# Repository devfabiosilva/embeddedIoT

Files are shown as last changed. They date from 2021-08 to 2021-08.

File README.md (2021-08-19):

# embeddedIoT
My old project for IoT and automation 8 bit system

## Brief

This is my fisrt and old discontinued home embedded 8bit iot for control, monitoring and automation working 24/7 since 2014 open hardware

## Details

### - Hardware specification

  - Project [folder](/hardware)
  - Last update 2014-04-01

  TODO

### - Firmware specification

  - Project [folder](/firmware_ver1.5)
  - Last update 2015-07-01

### - Uart for IoT using PySerial (Monitoring)

  - Project [folder](/UartForIoT)
  - RS232 protocol using [PySerial](https://pypi.org/project/pyserial/)
  - Script type reads events RS232 -> USB -> TCP
  - Commands using [this reference for reading events](/embeddedsystem.pdf) pages: 32-35
  TODO

## Snapshots

<p align="center">
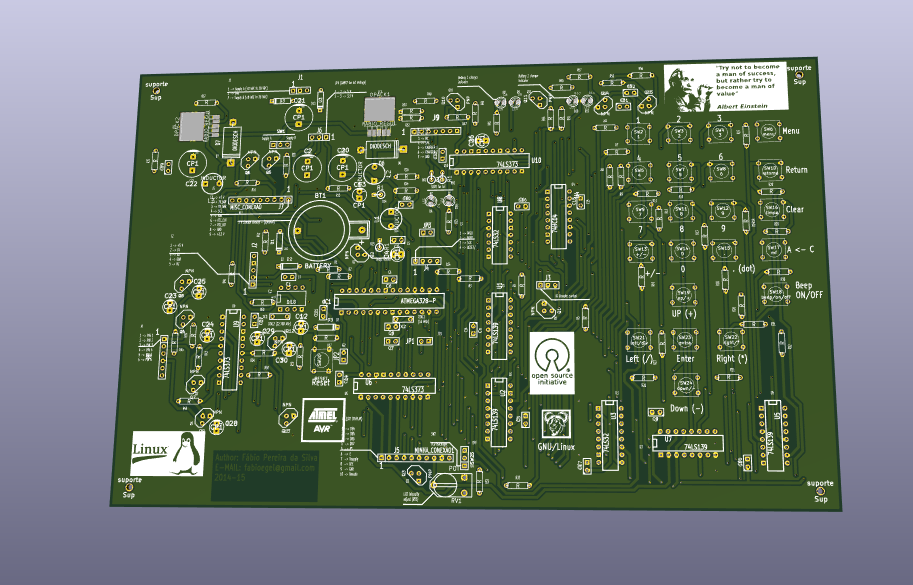
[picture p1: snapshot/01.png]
  
</p>

<p align="center">
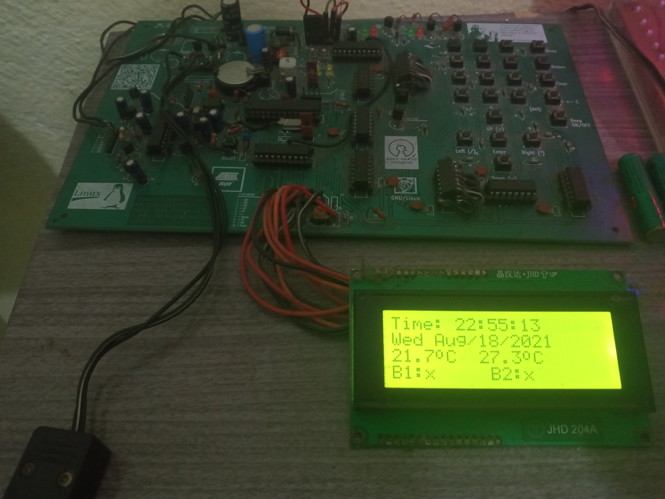
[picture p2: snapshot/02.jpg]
  
</p>

## Specifications

## Export GERBER files

## Installing AVR C (avr-gcc) and compiling firmware

## Upload firmware

## Running Python to read events from RS 232

## License

  - MIT

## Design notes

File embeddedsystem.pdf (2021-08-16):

## An 8-bit AVR EMBEDDED SYSTEM

## Features

- Six independent pins automation through IR remote control, keyboard or IoT.
- Six independent programmable pins controlled by temperature, battery charger sensors and timers
- Real time clock with alarm
- Calendar
- Default and Scientific Calculator
- 20x4 LCD display
- Two Battery Charger
- Bilingual language support (English/Portuguese)
- 16 MHz MCU clock speed using ATMEGA 328pu microcontroller
- Full IR control available through ProntoHEX code allowing access through IR devices.
- Automotive, Home and Industry versions available in a single hardware
- Low cost components

Author: Fábio Pereira da Silva 03/29/2015

Rev.: 2

1

"Try not to become a man of success, but rather try to become a man of value

Albert Einstein

2

Figure 1: Basic Block Diagram

## Overview

This Embedded System was developed with ATMEGA 8-bit family microcontroller. Due to its capacity of processing it's possible to do amazing stuffs. This Embed System is an automated controller that you can control 6 (six) home/industry appliances individually easily by temperature, timer and by user through infrared (remote control or cellphone) or even IoT (optional). In Figure 1 is seen the basic block using ATMEGA 328pu 8-bit microcontroller.

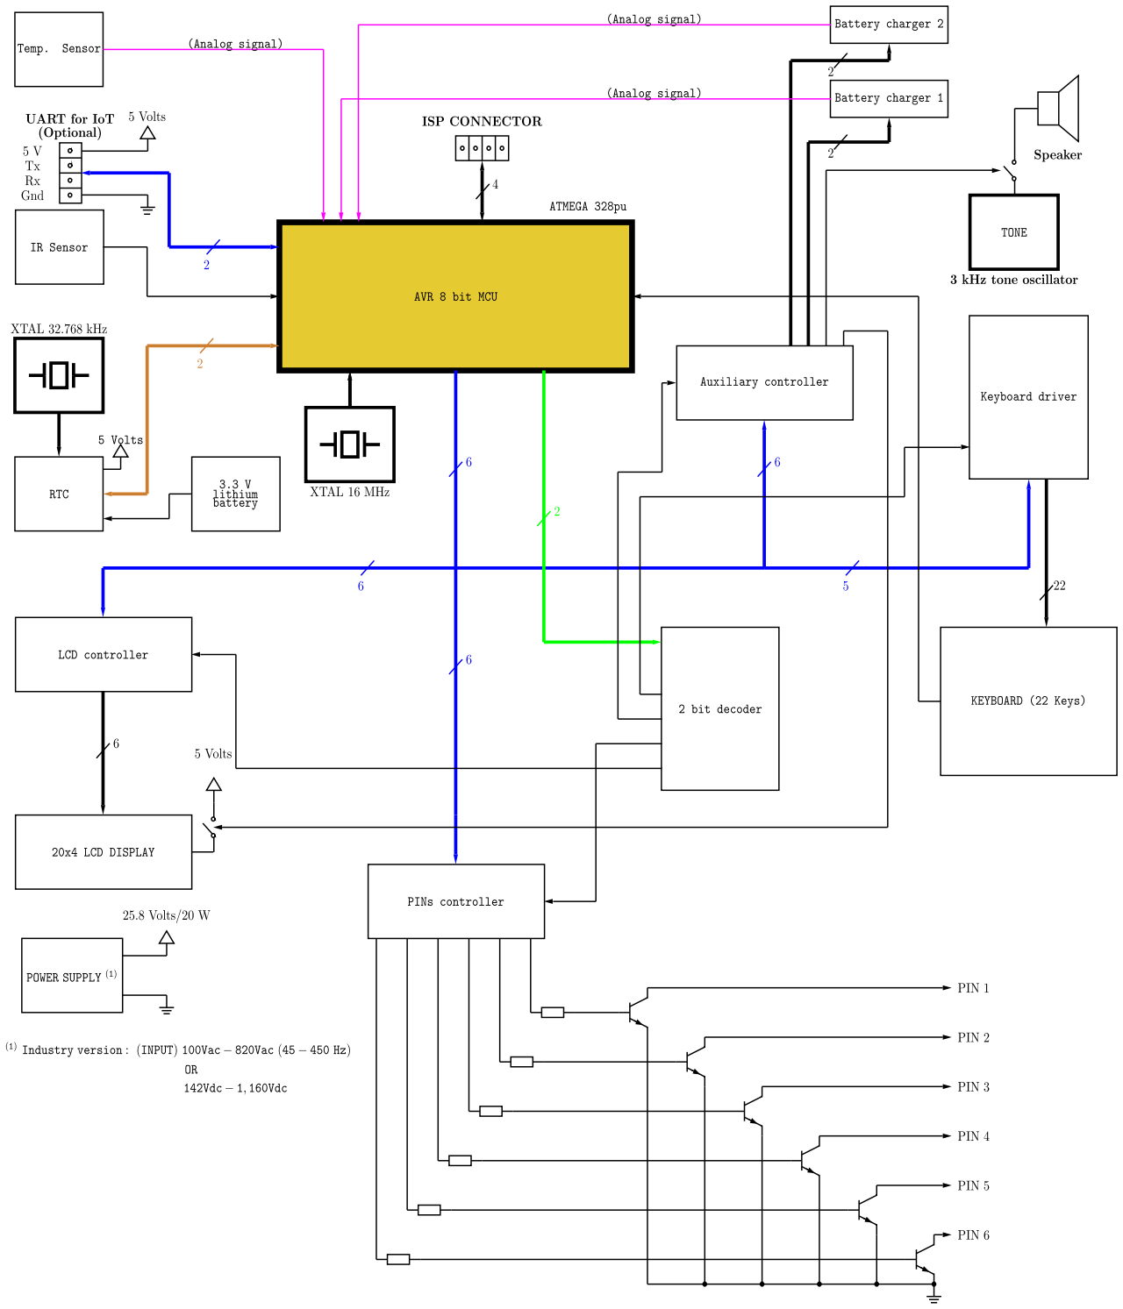
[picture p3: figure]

3

## Hardware interface and connections

Before turn on this Embedded System you should know this hardware interface and basic connections. Figure 2 shows this 8-bit Embedded System Hardware.

10

Figure 2: 8-bit hardware AVR architecture

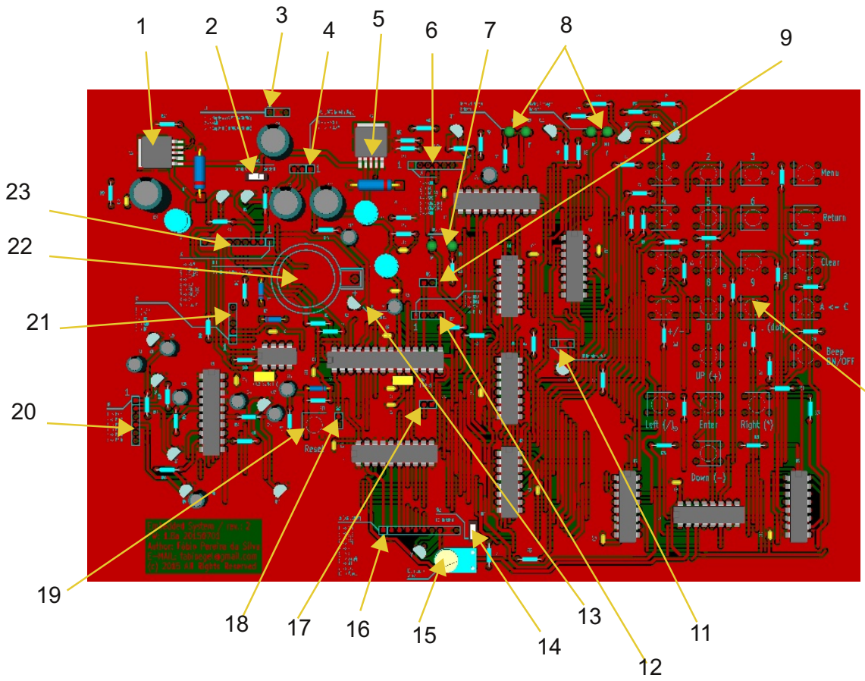
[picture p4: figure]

Table 1 shows detailed connections name and descriptions of the Figure 2.

4

## Hardware settings

You need configure hardware to interface other devices. This hardware also provides two post regulated power supply 3.3 V (2 A) and 5 V (1.5 A) to others devices such as Arduino, Raspberry PI, Beagle Bone and many others from 8 Vdc ~ 38 Vdc (automotive application) and 100 Vac ~ 820 Vac (45-450 Hz) or even 142 Vdc to 1160 Vdc (Home and Industrial application) using a special high range SMPS (Switching Mode Power Supply) designed by me.

| Name | Description
1 | 3.3 V regulator | Provides 3.3 V (2 A) to external devices
2 | SW1 Input power selector | Selects one of two inputs power supply (A or B)
3 | 2 (two) Input power | Input A and B => Power supply voltage 8 Vdc to 38 Vdc
4 | JP4 (UART2 for IoT Voltage) | Selects operation voltage (3.3 V or 5V) for UART2 for IoT
5 | 5 V regulator | Provides 5 V (1.5 A) for internal and external circuit devices
6 | J8 output interface | Output interface (Battery 1 and 2 chargers and Speaker)
7 | RX and TX indicator leds | Indicates Rx and Tx transmitting data
8 | Battery 1 and 2 indicator leds | Indicates Battery 1 and 2 status
9 | JP3 | Normal operation= (short) / ISP programming = (open)
10 | Keyboard | Numerical and functions keyboard
11 | IR (Infrared Sensor) | For remote control access
12 | J3 (ISP interface) | For ISP interface (firmware update/debug/programming)
13 | T1 | External temperature sensor
14 | SW2 | LCD Backlight Switch
15 | RV1 | LCD intensity adjust
16 | J4 | Output LCD interface
17 | JP1 | Normal operation= (short) / ISP programming = (open)
18 | JP2 | Normal operation= (short) / ISP programming = (open)
19 | Reset button | Resets microcontroller
20 | J6 | PIN's output interface
21 | J2 | UART for IoT interface
22 | Real time clock backup | Lithium Battery (optional) for Real Time Clock (RTC)
23 | J5 | Input/Output interface

## Table 1: Connections name and descriptions

5

This devices offers 9 connectors to interface others components or devices

Tables 2, 3, 4, 5, 6, 7 and 8 shows each input/output interface.

J1 | Input type | Description
1 | Power supply A | Input voltage 8 Vdc to 38 Vdc
2 | GND | Ground
3 | Power Supply B | Input voltage 8 Vdc to 38 Vdc

## Table 2: Input power supply connection (J1)

J2 (UART1 for IoT) Input/output type | | Description
1 | +5 V | Output power supply
2 | Tx (Output) | UART1 for IoT transmit
3 | Rx (Input) | UART1 for IoT receive
4 | GND | Ground
5 | NC | No connection
J3 (ISP Programming) | Input/output type | Description
1 | MISO (output) | Data output
2 | MOSI (Input) | Data input
3 | SCK (Input) | Clock from master from programmer
4 | RESET (Input) | Reset inverted logic from programmer

## Table 3: UART1 for IoT and +5 V supply connection (J2)

## Table 4: ISP connection (J3)

6

J4 (LCD display interface) | Output type | Description
1 ~ 4 | DB4 ~ DB7 | Four high order bits for HD44780 LCD controller
5 | RS | Select register
6 | E | Data write
7 | Vsupply | +5 V Power supply for LCD controller
8 | VEE | LCD intensity
9 | GND | Ground
10 | Vanode | +5 V power supply for LCD backlight
J5 (I/O interface) | Input/Output type | Description
1 | +5 V (output) | Output power supply. Provides 1.5 A for external devices
2 | TX (output) | Inverted output (UART2 for IoT)
3 | RX (input) | Inverted input (UART2 for IoT)
4 | SCL (output) | Output I 2C clock
5 | SDA (input/output) | Input/output I 2C data
6 | RTC_CLK (output) | Real time clock frequency (32.768 Hz, 1024 Hz, 32 Hz or 1Hz) Refer PCF 8563 for details
7 | RTC_INT (output open drain) | Inverted real time clock interrupt. Refer PCF 8563 for details
8 | GND | Ground
9 | +3.3 V (output) | Output power supply. Provides 2 A for external devices.

## Table 5: LCD display interface connection (J4)

## Table 6: Input/Output interface connection (J5)

7

J6 (PINs output) | Output type | Description
1~6 | PIN1~PIN6 (output open collector) | Provides 90 mA (each pin) output driver. Maximum voltage is 40 V
J7 (Output interface) | Output type | Description
1 | GND | Ground
2 | NC | No connection
3 | NC | No connection
4 | SPK | Speaker
5 | CHARGER 1 | Battery Charger 1 output (47 mA inicial charger current)
6 | CHARGER 2 | Battery Charger 2 output (47 mA inicial charger current)
7 | GND | Ground

## Table 7: Output interface connection (J6)

## Table 8: Output interface connection (J7)

8

## Turning on this Embedded System

After turn on the system will shown in LCD display the following message (Figure 3).

Current time hh:mm:ss

Current date

External
temperature sensor
T1

indicator

Internal (MCU)
temperature sensor T2
indicator

Battery 1 (B1

) charger
indicator in % charging. 'x' for no battery.

Battery 2 (B2

) charger
indicator in % charging. 'x' for no battery.

## Accessing Menu for settings

When pressing <MENU> button will shown 6 (six) options. Press 1 to access Time adjust, weekday (calendar) or alarm, 2 for pins configuration, 3 for detailed sensor measures, 4 for default or scientific calculator, 5 for (others) language support, temperature sensor, and configure UART for IoT, security, UART parity and user password. Finally press 6 for about firmware and hardware information. Full access at UART is limited. Only ROOT has full access by keyboard or remote control.

Figure 3: Embedded System Display

Figure 4: Embedded System inicial MENU

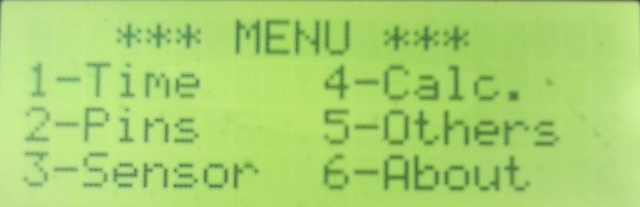
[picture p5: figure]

9

## Setting date and time

To set date/time press <MENU> buttom and press 1 (one) for Time and 1 (one) again to set Date/Time adjust.

Figure 5: DATE and TIME ADJUST

Current date in
yyyy/mm/dd

Current time in
hh:mm:ss

Cursor for typing Date and Time

## Example for Date/Time Adjust

If you want to set Time and Date to May, 14/2015 12:30:00 you must to type 20150514123000 and press <OK> button. You must type yyyymmddhhmmss where yyyy is current year, mm is current month, dd is current day, hh is current hour, mm is current minute and finally ss is current second. If you type anything wrong just press <CLEAR> button to clean Date/Time Adust. For year range is 1900 to 2099.

Figure 6: Date and time adjust example

Figure 7: EXAMPLE: Setting time and date to 12:30:00 May 14, 2015

10

## Weekday (calendar)

To access Weekday press <MENU> > press <1> (Time) > press <2> (Weekday). Display will show a cursor for Weekday command (figure 7 below).

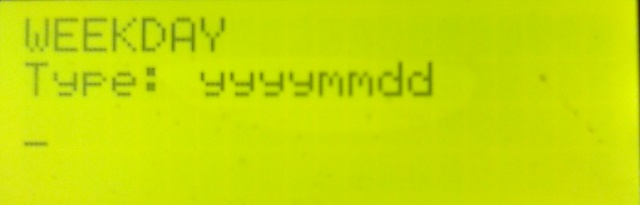
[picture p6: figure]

You must type yyyymmdd for yyyy year mm for month and dd for day

Example:

Which day was July, 4 1776? If you want to know, you must type 17760704 and press <OK> button. The answer is (Thu). It was on Thuesday.

Figure 7: Calendar (weekday)

Figure 8: Calendar example date (July, 6 1776)

## Alarm Setup

To configure alarm just press <MENU> > 1 (Time) > and finally press 3 (alarm) the following message will appear at LCD screen.

Command type: chhmm:

Where:
c = 0 (alarm disabled); c=1 (alarm enabled) hh for hour and mm for minutes

Last alarm in EEPROM memory

Figure 9: Alarm setup

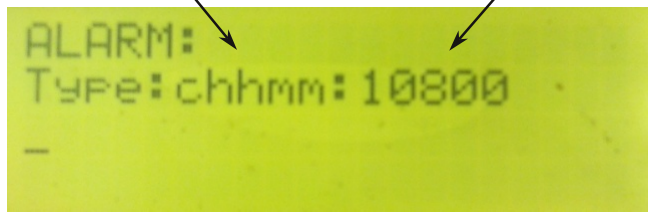
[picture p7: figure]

11

Example 1:

If you type 11910 the alarm will set for 19:10.

Example 2:

To turn off alarm just type 0 and press <OK>.

Figure 10: EXAMPLE: Setting alarm

Figure 11: EXAMPLE: Reset alarm

## Configuring PIN's

This Embedded System has 6 (six) PIN's that can be controlled individually by remote control using Pronto HEX code, remotely by IoT using commands from UART for IoT, by onboard keyboard, by sensors (4 sensors) or time. Each output PIN has two state (ON/OFF) and is open collector port that supports maximum voltage of 40 V and can drive maximum input current of 90 mA.

Figure 12: PIN's configuration menu

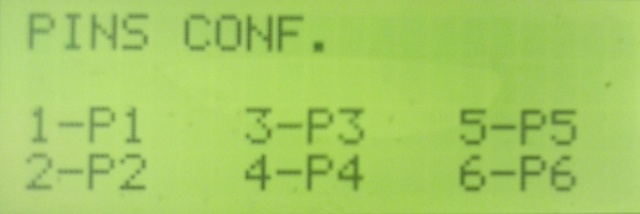
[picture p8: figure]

12

- Timer command:

To configure any pins to turn ON and/or OFF by timer you must type the following

Example 1 for timer command:

If you type 11235210016 and press <OK> button, the pin (in this example PIN 3 in figure 13 below) will always turn ON at 23:52 and always turn OFF at 00:16.

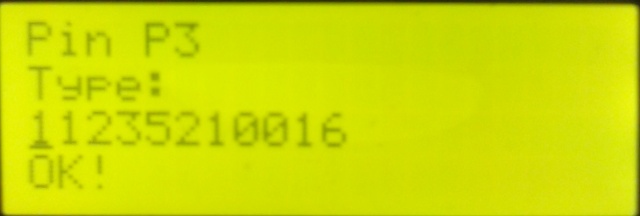
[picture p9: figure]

Example 2 for timer command:

If you type 11201800000 and press <OK> button, the pin (in this example PIN 5 in figure 14 below) will always turn ON at 20:18 (only). Y=0 (turn OFF command is DISABLED)

Figure 13: Timer command Example 1

Figure 14: Timer command Example 2

13

Example 3 for timer command:

If you type 10000011325 and press <OK> button, the pin (in this example PIN 1 in figure 15) will always turn OFF at 13:25 (only). X=0 (turn ON command is DISABLED).

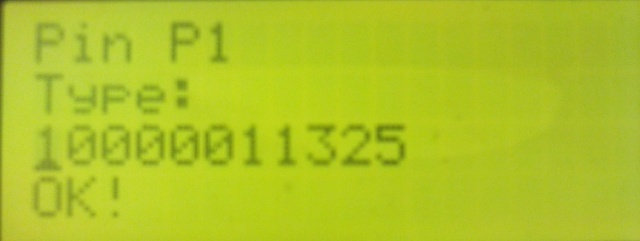
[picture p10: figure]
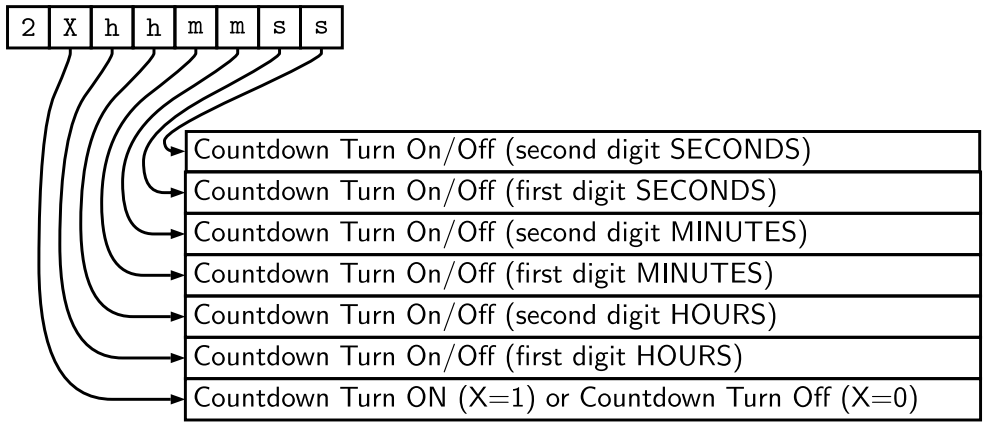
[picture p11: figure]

Example 1 for countdown timer command:

If you type 20001530 and press <OK> button, the pin (in this example PIN 6 in figure
16) will turn off after 15 minutes and 30 seconds (countdown timer).
- Countdown timer command:

To configure any pins to turn ON and/or OFF by countdown just type the following command 2 X h h m m s s for desired pin(s), where:

Figure 15: Timer command Example 3

Figure 16: Countdown timer command Example 1

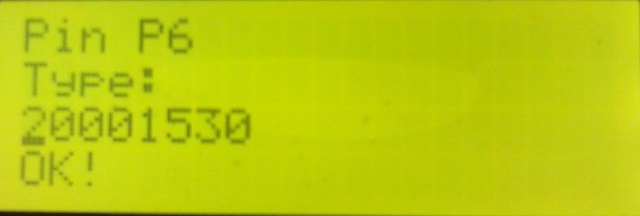
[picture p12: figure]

14

Example 2 for countdown timer command:

If you type 21010000 and press <OK> button, the pin (in this example PIN 6 in figure
17) will turn on after 1 hour (countdown timer). Maximun countdown timer operation is also programmable for 17h59m59s.
- Ciclic (periodic) command:

To configure any pins to turn ON and OFF periodicly, just type the following command 3 h1

h1 m1 m1

s1

s1

h2

h2 m2 m2

s2

s2

for desired pin(s), where:

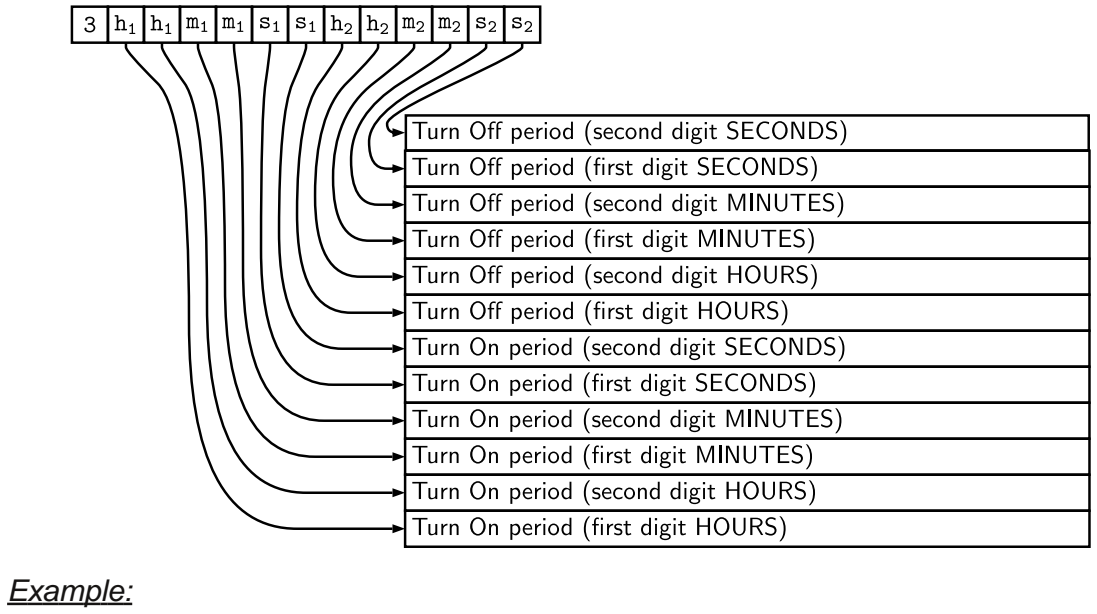
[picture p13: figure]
Example:

If you type 3000001000001 and press <OK> button, the pin (in this example PIN 6 in figure 18) will keep ON each 1 (one) second and will keep OFF each 1 (one) second. In other words, PIN 6 in this configuration oscillates at 1/2 Hertz. Maximun ciclic operation is also programmable for 17h59m59s.

Figure 17: Countdown timer command Example 2

15

## Temperature sensor command ( T1

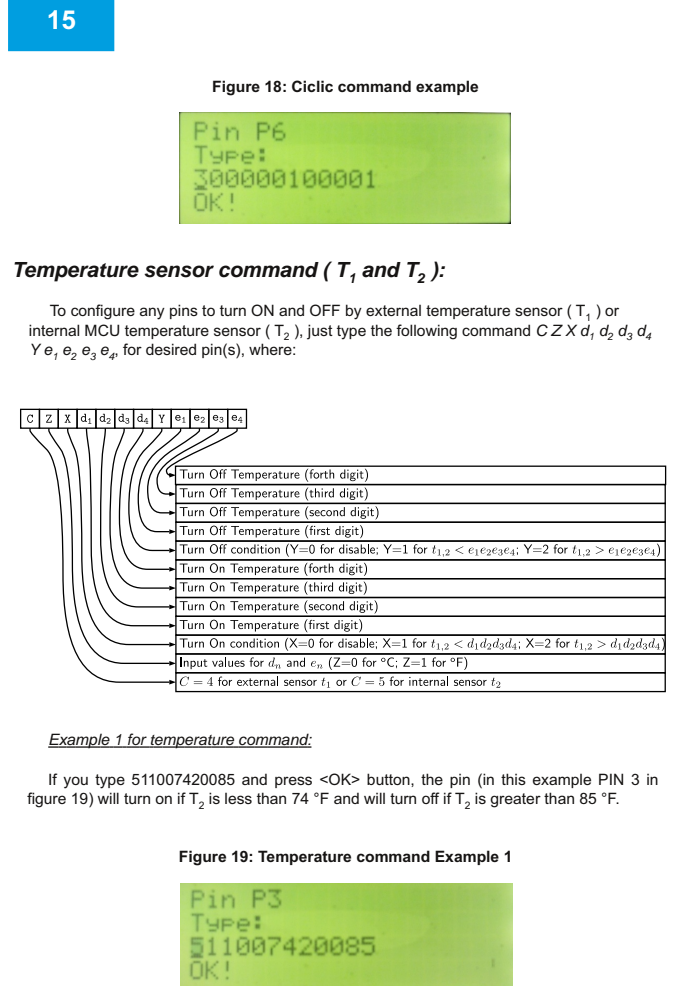
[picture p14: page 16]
and T2

Figure 18: Ciclic command example

To configure any pins to turn ON and OFF by external temperature sensor ( T1
internal MCU temperature sensor ( T2

), just type the following command C Z X d1

, for desired pin(s), where:

Example 1 for temperature command:

If you type 511007420085 and press <OK> button, the pin (in this example PIN 3 in
figure 19) will turn on if T2

is less than 74 °F and will turn off if T2

is greater than 85 °F.

Figure 19: Temperature command Example 1

16

Example 2 for temperature command:

If you type 51200001-040 and press <OK> button, the pin (in this example PIN 5 in figure 20) will turn on if T2

is greater than 0 °F and will turn off if T2

is less than -40 °F.

## Battery charger sensor command ( B1

## and B2

):

To configure any pins to turn ON and/or OFF by battery sensor B1

or B2

, just type the
following command.

Figure 20: Temperature command Example 2

Example 3 for temperature command:

If you type 402003500000 and press <OK> button, the pin (in this example PIN 6 in figure 21) will turn on if T1

is greater than 35 °C. NOTE: turn off condition (Y=0) is disable. Then turn on (only) is enabled.

Figure 21: Temperature command Example 3

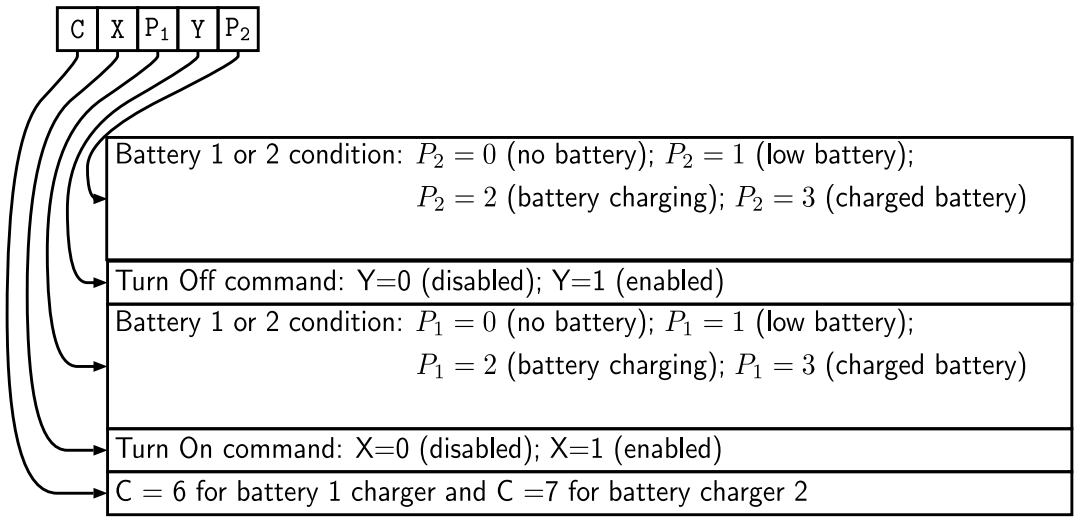
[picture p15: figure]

17

Example 1 for battery charge command:

If you type 61113 and press <OK> button, the pin (in this example PIN 3 in figure 22) will turn on if battery in charger 1 is uncharged and will turn off if battery in charger 1 is charged.

Figure 22: Battery charger example 1

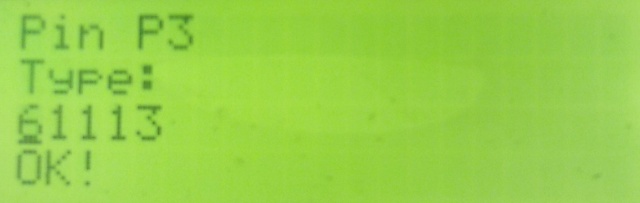
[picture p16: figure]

Example 2 for battery charger:

If you type 71310 and press <OK> button, the pin (in this example PIN 4 in figure 23) will turn on if battery in charger 2 is charged and will turn off if battery in charger 2 is released.

Example 3 for battery charger:

If you type 60013 and press <OK> button, the pin (in this example PIN 6 in example 24) will turn off if battery in charger 1 is charged.

Figure 23: Battery charger example 2

Figure 24: Battery charger example 3

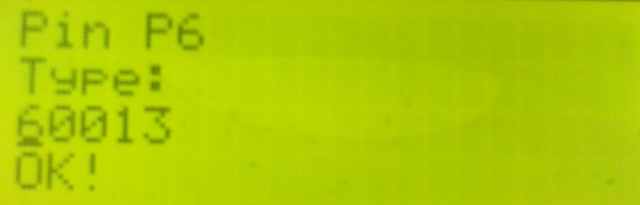
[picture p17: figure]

18

## Resetting pin(s)

If you want to reset any pin(s), just type 0 and press <OK>. Now pin will be controlled only by user from IoT, Infrared or Keyboard.

Example:

If you type 0 and press <OK>. The pin (in this example PIN 6 in figure 25) will be controlled by user via IoT, remote control or keyboard.

## Sensor panel

To access real time sensors press <MENU> and press <3> (Sensor). The system will provide measurements of four sensors (Battery 1 and 2 charger voltage, internal (MCU) and external temperature T1 and T2 respectively).

Figure 25: Resetting pin(s)

Figure 26: Sensor panel (real time measuring)

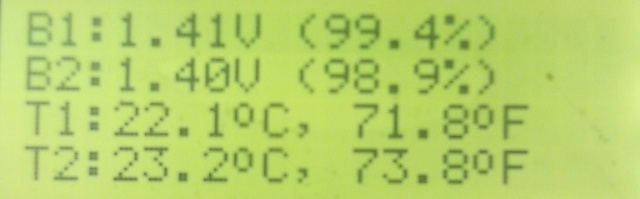
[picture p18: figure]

## Calculator menu

To access calculator option just type <MENU> > <4> (Calc.). Default and Scientific calculator provides 3 (three) variables A (or 'x'), B and C where A (or 'x') is first value, B is second value and C is result of operation. Input and result values are in float point unit is (32 bits) or 7 digit precision.

19

## Default calculator

To access default calculator just press <MENU> > <4> (Calc.) > <1> (Default calculator).

In default calculator is possible perform 4 (four) math basic operations (+) addition, () subtraction, (*) multiply and (/) divide.

Example:

If you want divide 50 by 3 you type <5> > <0> > <enter> and then press <divide> and then press <3> and <enter> result is shown in figure 28.

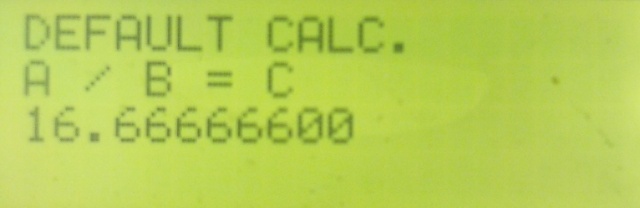
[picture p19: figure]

## Scientific calculator

There are 23 math functions: exp(x), ln(x), ln(x)/C, sqrt(x), cbrt(x), sin(x), cos(x), tan(x), sind(x), cosd(x), tand(x), asin(x), acos(x), atan(x), asind(x), acosd(x), atand(x), C<-A, hyp(C, A), mod(C,A), sinh(x), cosh(x) and tanh(x).

Some examples: Printing in the screen some basics values.

Example 1 for scientific calculator:

If you press <up> or <down> and select exp function and type <1> and press <enter>. Result is an approximation of e = 2.7182817...

Figure 27: Calculator menu

Figure 28: Basic calculator example

20

Example 2 for scientific calculator

If you press <up> or <down> and select sqrt function and type <2> and press <enter>. Result is an approximation of ≈ 1.4142135...

Example 3 for scientific calculator

Calculating π using trigonometric function in this case acos(-1)= π = 3.1415927...

Figure 29: Scientific calculator example 1

Figure 30: Scientific calculator example 2

Figure 31: Scientific calculator example 3

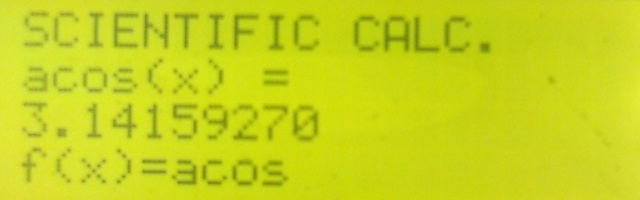
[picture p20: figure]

Example 4 for scientific calculator

But now, if you want to calculate log10

(2)? This scientific calculator does not provide such function but you can calculate easily using two steps by using one logarithm property:

step 1: Select ln(x) function and type 10 and press <enter>. Result, in this case ln(10) is stored in variable C.
step 2: Select ln(x)/C function and type 2 and press <enter>. Result is an approximation of log10
(2)=0.30102998...

21

Example 5 for scientific calculator

But now, if you want to calculate hypotenuse of 3 and 6? To calculate it you must call function C<-A and call hyp(C, A) using two steps because you have to pass two variables
(3) and (6).
step 1: Select C<-A function and type 3 and press <enter>. Value 3 is stored in C variable.
step 2: Select hyp(C,A) function and type 6 and press <enter>. Result is an approximation of hyp(3,6)=6.7082038...

Figure 32: Scientific calculator example 4 (step 1)

Figure 33: Scientific calculator example 4 (step 2)

Figure 34: Scientific calculator example 5 (step 1)

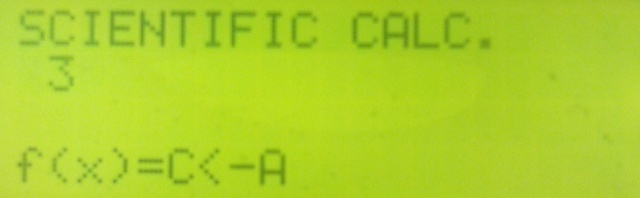
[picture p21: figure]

Figure 35: Scientific calculator example 5 (step 2)

22

## Changing language system

To change language interface you must first access other functions menu. So you must type <MENU> > <5> > <1> and select your available language (US English) or (Brazilian Portuguese). Press <1> for English (US) or press <2> for Portuguese (BR).

## Other configuration

To access other configuration to have special access like language interface, change unity measurements, configure IoT and security you must type <MENU> > <5> and then you will see as figure below (figure 36).

Figure 36: Other configurations (special options)

Figure 37: Selecting language interface

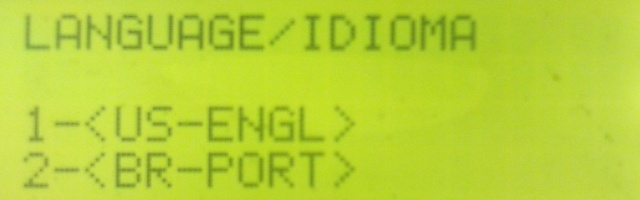
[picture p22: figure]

## Temperature measurements

You can read temperature sensors T1 (external) and T2 (MCU internal) in (°C) degree Celsius (default) or in (°F) degree Fahrenheit. To modify both temperature indicator type <MENU> > <5> > <2>. Then choose 1 (for °C) or (2 for °F).

Figure 38: Selecting realtime system measurement

23

## UART for IoT

You can use UART for IoT to access this embedded system to control PINs output, read or write SRAM and EEPROM memories, LCD control, read sensors, reset MCU, configure hardware and read or set date and time remotely. To have entire or partial control for remote control via IoT you must access UART for IoT option. You can do it only locally (ROOT). For details see (UART for IoT user security).

To have an access to UART for IoT you must type <MENU>, <5> > <3>.

If you set a password then it will be requested every time you access UART for IoT menu. See setting password for details.

In UART for IoT Menu, there are 3 (three) options: 1 (configure port), 2 (Security attributes), 3 (Set PASSWORD)

## Configure port menu

If you want to access UART for IoT you must before configure speed, parity, security attributes and user password (optional)

Figure 39: Access UART for IoT (with password)

Figure 40: Access UART for IoT (no password)

Figure 41: Configure port menu

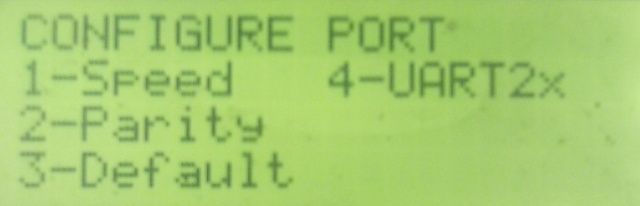
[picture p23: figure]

24

## Setting speed to UART for IoT

To set speed (baund rate) just type in UART for IoT menu <1> > <1>. Default value is 5 (19600 bps). Table 9 below shows 16 values of UART speed available.

Speed | Baund rate (bps)

0 300

1 600

2 1200

3 2400

4 4800

5 9600 (default)

6 14400

7 19200

8 28800

9 38400

10 50000

11 76800

12 230400

13 250000

14 500000

15 1000000

## Table 9: UART for IoT speed

Figure 42: Setting speed

25

## Parity settings

To set parity just type in UART for IoT menu <1> and <2>. There are 3 options available: 1- None (default), 2 Even and 3 Odd. User can modify these settings for error detection in UART communication port.

Figure 43: Setting parity

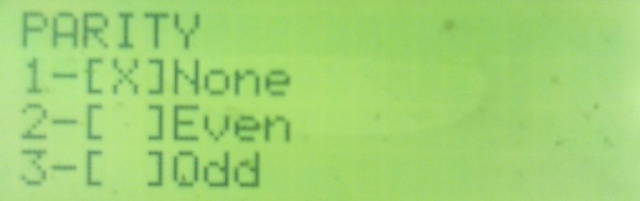
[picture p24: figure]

## Loading defaut values

To load default values, just type in UART for IoT menu <1> and <3>. A message "Load default?" with two answer available will apear: 1- Yes and 2 No. If you type 1 (Yes), all the configurations port will set to default (Speed = 5, Parity = None and UART2x=Disabled).

Figure 44: Load default option

## Enabling/Disabling UART2x

You can simply double (2x) speed communication to UART. To access UART2x press in UART for IoT menu <1> (Configure port) and <4> (UART2x). Press 1 to Enable UART2x or 2 to Disable UART2x. If UART2x is enabled, communication speed in Table 9 will be multiplied by 2 and the new range will be (600 to 2,000,000 bauds/s). Default value to UART2x = Disabled. UART for IoT PORT 2 will not work at highest speed due to hardware limitations. Even in PORT 1 errors may occur in high speed communication.

Figure 45: Enable/Disable UART2x

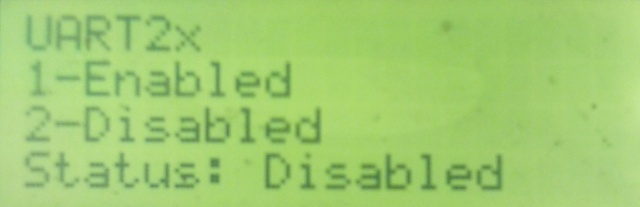
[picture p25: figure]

26

Function | Description | Values
x | No function (reserved) | Don't care 0 or 1
N | Read sensors | N=0b0 (access denied), N=0x1 (read all sensors)
T | Two wire access | T=0b0 (access denied), T=0b1 (Two wire read and write access)
S1S0 | SRAM access | S1S0 =0b00 (access denied), S1S0 =0b01 (read only), S1S0 =0b10 (write only), S1S0 =0b11 (read/write)
En | UART for IoT access | En=0b0 (UART for IoT) disable, En=0b1 (UART for IoT) enebled.
F | Program (FLASH) (read only) | F=0b0 (access denied), F=0b1 (FLASH read only enabled)
R | Reset MCU | R=0b0 (reset MCU disabled), R=0b1 (reset MCU enabled)
E1E0 | EEPROM access | E1E0 =0b00 (access denied), E1E0 =0b01 (read only), E1E0 =0b10 (write only), E1E0 =0b11 (read/write)
P1P0 | PIN access | P1P0 =0b00 (access denied), P1P0 =0b01 (read only), P1P0 =0b01 (write only), P1P0 =0b11 (read/write)
L | LCD access/control | L=0b0 (access denied), L=0b1 (LCD control access/control)
D1D0 | Date and time access | D1D0 =0b00 (access denied), D1D0 =0b01 (read only), D1D0 =0b10 (write only), D1D0 =0b11 (read write)

## UART for IoT user security

User can control remote access from read/write and access command using permission configuration. For security access into UART for IoT menu type <2> (Security attributes) <1> (Permission).

You can access FLAG value (16 bits) stored in EEPROM at address 0x3FE (low bits) and 0x3FF (high bits). Each bit(s) has an especial attribute for access, read or write commands for UART for IoT. See Table 10 for permission bits details. User value is present in decimal and hexadecimal see figure 46 below.

Flag | N | T | x | S1 | S0 | En | F | R | E1 | E0 | P1 | P0
x | L | D1 | D0
MSB | LSB
15 | 0

Figure 46: 16 bit security flags for remote access

## Table 10: Flag bits function and description

27

## Setting user PASSWORD

For managing (set, modify, clear) user password type into UART for IoT menu 3-> Set PASSWORD.

Figure 47: Setting IoT security

## UART for IoT user security (load default)

For default values of security attributes type into UART for IoT menu 2-> (Security attributes) 2- Default. Will apear "Load default?" question. Then type 1 for Yes (Load default) or 2 (No) to keep user security settings.

Default value is FLAG=33873 (0x8451). This means UART for IoT is enabled for read only Pins, Datetime, EEPROM memory and user can access all sensors.

Figure 48: Load default option

Figure 49: Setting user PASSWORD

If there is no Password or it's your first time setting password then will appear a message below (Figure 50). And then you will need to type the old password.

28

## Information about firmware and hardware

If you type <MENU> > <6> you have access to information about current firmware and hardware date and version. Firmware is upgradable by ISP (In Serial Programming) interface.

Type your new password and press <ENTER>. A confirm message password will appear and type <ENTER>. User password now is set. Now, you will need password to access UART for IoT.

Figure 50: Setting a new PASSWORD

Figure 51: Retyping a new PASSWORD

Figure 52: About information

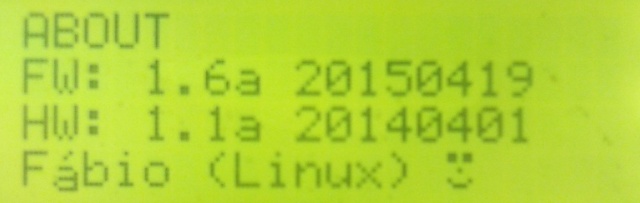
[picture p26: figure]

29

## Characteristics

CPU architecture: AVR 8-bit RISC

CPU speed: 16 MHz

Total memory: 32 kB (Flash)

Total SRAM memory: 2 kB

Total EEPROM memory: 1 kB

Interrupts: 6 interrupts (3 external + 3 internal)

Hardware Version: 1.1a (20140401)

Firmware Version: 1.5a (20150419) (upgradable via ISP interface)

Languages support: English (USA) / Portuguese (Brazil)

Temperature unity measurements: °F (degree Fahrenheit) or °C (degree Celsius)

Operation voltages:

8 to 38 Vdc

Lithium Battery 3.3 V (optional) for Real Time Clock

Industry and Home Version*:100Vac 820Vac (45-450Hz) or 142Vdc 1160Vdc

*A Very High Voltage Range Switching Mode Power Supply for Embedded System. See documentation for details. This power supply uses only 3 (three) transistors e no integrated circuits.

30

Code IR | Pronto Hex code
0 | 0000 0066 0000 006b 0168 00b3 0017 0017 0017 0017 0017 0017 0017 0017 0017 0017 0017 0017 0017 0017 0017 0017 0017 0017 0001 002c 0017 0017 0001 002c 0017 0017 0001 002c 0017 0017 0001 002c 0017 0017 0001 002c 0017 0017 0001 002c 0017 0017 0001 002c 0017 0017 0001 002c 0017 0017 0017 0017 0017 0017 0017 0017 0001 002c 0017 0017 0017 0017 0017 0017 0001 002c 0017 0017 0017 0017 0001 002c 0017 0017 0001 002c 0017 0017 0001 002c 0017 0017 0017 0017 0001 002c 0017 0017 0001 002c 0017 0017 0017 0017 0001 002c 0017 0017 0001 002c
1 | 0000 0066 0000 006b 0168 00b3 0017 0017 0017 0017 0017 0017 0017 0017 0017 0017 0017 0017 0017 0017 0017 0017 0017 0017 0001 002c 0017 0017 0001 002c 0017 0017 0001 0030 0017 0017 0001 002c 0017 0017 0001 002c 0017 0017 0001 002c 0017 0017 0001 002c 0017 0017 0001 002c 0017 0017 0001 002c 0017 0017 0017 0017 0017 0017 0001 002c 0017 0017 0017 0017 0017 0017 0017 0017 0017 0017 0017 0017 0001 002c 0017 0017 0001 002c 0017 0017 0017 0017 0001 002c 0017 0017 0001 002c 0017 0017 0001 002c 0017 0017 0001 002c 0017 0017 0001 002c
2 | 0000 0066 0000 006b 0168 00b3 0017 0017 0017 0017 0017 0017 0017 0017 0017 0017 0017 0017 0017 0017 0017 0017 0017 0017 0001 002c 0017 0017 0001 002c 0017 0017 0001 002c 0017 0017 0001 002c 0017 0017 0001 002c 0017 0017 0001 002c 0017 0017 0001 002c 0017 0017 0001 002c 0017 0017 0001 002c 0017 0017 0017 0017 0001 002c 0017 0017 0001 002c 0017 0017 0001 002c 0017 0017 0017 0017 0017 0017 0017 0017 0017 0017 0001 002c 0017 0017 0017 0017 0017 0017 0017 0017 0001 002c 0017 0017 0001 002c 0017 0017 0001 002c 0017 0017 0001 002c
3 | 0000 0066 0000 006b 0168 00b3 0017 0017 0017 0017 0017 0017 0017 0017 0017 0017 0017 0017 0017 0017 0017 0017 0017 0017 0001 002c 0017 0017 0001 002c 0017 0017 0001 002c 0017 0017 0001 002c 0017 0017 0001 002c 0017 0017 0001 002c 0017 0017 0001 002c 0017 0017 0001 002c 0017 0017 0001 002c 0017 0017 0001 002c 0017 0017 0001 002c 0017 0017 0001 002c 0017 0017 0001 002c 0017 0017 0017 0017 0017 0017 0017 0017 0017 0017 0017 0017 0017 0017 0017 0017 0017 0017 0001 002c 0017 0017 0001 002c 0017 0017 0001 002c 0017 0017 0001 002c
4 | 0000 0066 0000 006b 0168 00b3 0017 0017 0017 0017 0017 0017 0017 0017 0017 0017 0017 0017 0017 0017 0017 0017 0017 0017 0001 002c 0017 0017 0001 002c 0017 0017 0001 002c 0017 0017 0001 002c 0017 0017 0001 002c 0017 0017 0001 002c 0017 0017 0001 002c 0017 0017 0001 002c 0017 0017 0001 002c 0017 0017 0017 0017 0017 0017 0001 002c 0017 0017 0001 002c 0017 0017 0017 0017 0017 0017 0017 0017 0017 0017 0001 002c 0017 0017 0001 002c 0017 0017 0017 0017 0017 0017 0001 002c 0017 0017 0001 002c 0017 0017 0001 002c 0017 0017 0001 002c
5 | 0000 0066 0000 006b 0168 00b3 0017 0017 0017 0017 0017 0017 0017 0017 0017 0017 0017 0017 0017 0017 0017 0017 0017 0017 0001 002c 0017 0017 0001 002c 0017 0017 0001 002c 0017 0017 0001 002c 0017 0017 0001 002c 0017 0017 0001 002c 0017 0017 0001 002c 0017 0017 0001 002c 0017 0017 0001 002c 0017 0017 0001 002c 0017 0017 0017 0017 0001 002c 0017 0017 0001 002c 0017 0017 0017 0017 0017 0017 0017 0017 0017 0017 0017 0017 0001 002c 0017 0017 0017 0017 0017 0017 0001 002c 0017 0017 0001 002c 0017 0017 0001 002c 0017 0017 0001 002c
6 | 0000 0066 0000 006b 0168 00b3 0017 0017 0017 0017 0017 0017 0017 0017 0017 0017 0017 0017 0017 0017 0017 0017 0017 0017 0001 002c 0017 0017 0001 002c 0017 0017 0001 002c 0017 0017 0001 002c 0017 0017 0001 002c 0017 0017 0001 002c 0017 0017 0001 002c 0017 0017 0001 002c 0017 0017 0001 002c 0017 0017 0017 0017 0017 0017 0017 0017 0001 002c 0017 0017 0017 0017 0017 0017 0017 0017 0017 0017 0001 002c 0017 0017 0001 002c 0017 0017 0001 002c 0017 0017 0017 0017 0001 002c 0017 0017 0001 002c 0017 0017 0001 002c 0017 0017 0001 002c
7 | 0000 0066 0000 006b 0168 00b3 0017 0017 0017 0017 0017 0017 0017 0017 0017 0017 0017 0017 0017 0017 0017 0017 0017 0017 0001 002c 0017 0017 0001 002c 0017 0017 0001 002c 0017 0017 0001 002c 0017 0017 0001 002c 0017 0017 0001 002c 0017 0017 0001 002c 0017 0017 0001 002c 0017 0017 0001 002c 0017 0017 0001 002c 0017 0017 0001 002c 0017 0017 0017 0017 0001 002c 0017 0017 0017 0017 0017 0017 0017 0017 0017 0017 0017 0017 0017 0017 0001 002c 0017 0017 0017 0017 0001 002c 0017 0017 0001 002c 0017 0017 0001 002c 0017 0017 0001 002c
8 | 0000 0066 0000 006b 0168 00b3 0017 0017 0017 0017 0017 0017 0017 0017 0017 0017 0017 0017 0017 0017 0017 0017 0017 0017 0001 002c 0017 0017 0001 002c 0017 0017 0001 002c 0017 0017 0001 002c 0017 0017 0001 002c 0017 0017 0001 002c 0017 0017 0001 002c 0017 0017 0001 002c 0017 0017 0017 0017 0001 002c 0017 0017 0017 0017 0017 0017 0001 002c 0017 0017 0017 0017 0017 0017 0017 0017 0001 002c 0017 0017 0017 0017 0001 002c 0017 0017 0001 002c 0017 0017 0017 0017 0001 002c 0017 0017 0001 002c 0017 0017 0001 002c 0017 0017 0001 002c
9 | 0000 0066 0000 006b 0168 00b3 0017 0017 0017 0017 0017 0017 0017 0017 0017 0017 0017 0017 0017 0017 0017 0017 0017 0017 0001 002c 0017 0017 0001 002c 0017 0017 0001 002c 0017 0017 0001 002c 0017 0017 0001 002c 0017 0017 0001 002c 0017 0017 0001 002c 0017 0017 0001 002c 0017 0017 0017 0017 0001 002c 0017 0017 0001 002c 0017 0017 0017 0017 0001 002c 0017 0017 0017 0017 0017 0017 0017 0017 0001 002c 0017 0017 0017 0017 0017 0017 0001 002c 0017 0017 0017 0017 0001 002c 0017 0017 0001 002c 0017 0017 0001 002c 0017 0017 0001 002c
. (dot) | 0000 0066 0000 006b 0168 00b3 0017 0017 0017 0017 0017 0017 0017 0017 0017 0017 0017 0017 0017 0017 0017 0017 0017 0017 0001 002c 0017 0017 0001 002c 0017 0017 0001 002c 0017 0017 0001 002c 0017 0017 0001 002c 0017 0017 0001 002c 0017 0017 0001 002c 0017 0017 0001 002c 0017 0017 0017 0017 0017 0017 0017 0017 0017 0017 0017 0017 0017 0017 0001 002c 0017 0017 0017 0017 0001 002c 0017 0017 0001 002c 0017 0017 0001 002c 0017 0017 0001 002c 0017 0017 0001 002c 0017 0017 0001 002c 0017 0017 0017 0017 0001 002c 0017 0017 0001 002c
+/ | 0000 0066 0000 006b 0168 00b3 0017 0017 0017 0017 0017 0017 0017 0017 0017 0017 0017 0017 0017 0017 0017 0017 0017 0017 0001 002c 0017 0017 0001 002c 0017 0017 0001 002c 0017 0017 0001 002c 0017 0017 0001 002c 0017 0017 0001 002c 0017 0017 0001 002c 0017 0017 0001 002c 0017 0017 0017 0017 0017 0017 0001 002c 0017 0017 0017 0017 0017 0017 0017 0017 0017 0017 0017 0017 0001 002c 0017 0017 0001 002c 0017 0017 0017 0017 0001 002c 0017 0017 0001 002c 0017 0017 0001 002c 0017 0017 0001 002c 0017 0017 0001 002c 0017 0017 0001 002c
<enter> | 0000 0066 0000 006b 0168 00b3 0017 0017 0017 0017 0017 0017 0017 0017 0017 0017 0017 0017 0017 0017 0017 0017 0017 0017 0001 002c 0017 0017 0001 002c 0017 0017 0001 002c 0017 0017 0001 002c 0017 0017 0001 002c 0017 0017 0001 002c 0017 0017 0001 002c 0017 0017 0001 002c 0017 0017 0001 002c 0017 0017 0017 0017 0017 0017 0001 002c 0017 0017 0017 0017 0017 0017 0001 002c 0017 0017 0017 0017 0017 0017 0001 002c 0017 0017 0001 002c 0017 0017 0017 0017 0001 002c 0017 0017 0001 002c 0017 0017 0017 0017 0001 002c 0017 0017 0001 002c
Up (+) | 0000 0066 0000 006b 0168 00b3 0017 0017 0017 0017 0017 0017 0017 0017 0017 0017 0017 0017 0017 0017 0017 0017 0017 0017 0001 002c 0017 0017 0001 002c 0017 0017 0001 002c 0017 0017 0001 002c 0017 0017 0001 002c 0017 0017 0001 002c 0017 0017 0001 002c 0017 0017 0001 002c 0017 0017 0017 0017 0017 0017 0001 002c 0017 0017 0001 002c 0017 0017 0017 0017 0017 0017 0001 002c 0017 0017 0017 0017 0001 002c 0017 0017 0001 002c 0017 0017 0017 0017 0017 0017 0001 002c 0017 0017 0001 002c 0017 0017 0017 0017 0001 002c 0017 0017 0001 002c
Down () | 0000 0066 0000 006b 0168 00b3 0017 0017 0017 0017 0017 0017 0017 0017 0017 0017 0017 0017 0017 0017 0017 0017 0017 0017 0001 002c 0017 0017 0001 002c 0017 0017 0001 002c 0017 0017 0001 002c 0017 0017 0001 002c 0017 0017 0001 002c 0017 0017 0001 002c 0017 0017 0001 002c 0017 0017 0017 0017 0017 0017 0017 0017 0017 0017 0017 0017 0017 0017 0017 0017 0017 0017 0001 002c 0017 0017 0001 002c 0017 0017 0001 002c 0017 0017 0001 002c 0017 0017 0001 002c 0017 0017 0001 002c 0017 0017 0001 002c 0017 0017 0001 002c 0017 0017 0001 002c
Left (/) | 0000 0066 0000 006b 0168 00b3 0017 0017 0017 0017 0017 0017 0017 0017 0017 0017 0017 0017 0017 0017 0017 0017 0017 0017 0001 002c 0017 0017 0001 002c 0017 0017 0001 002c 0017 0017 0001 002c 0017 0017 0001 002c 0017 0017 0001 002c 0017 0017 0001 002c 0017 0017 0001 002c 0017 0017 0001 002c 0017 0017 0017 0017 0001 002c 0017 0017 0017 0017 0001 002c 0017 0017 0017 0017 0017 0017 0017 0017 0017 0017 0001 002c 0017 0017 0017 0017 0001 002c 0017 0017 0017 0017 0001 002c 0017 0017 0001 002c 0017 0017 0001 002c 0017 0017 0001 002c
Right (*) | 0000 0066 0000 006b 0168 00b3 0017 0017 0017 0017 0017 0017 0017 0017 0017 0017 0017 0017 0017 0017 0017 0017 0017 0017 0001 002c 0017 0017 0001 002c 0017 0017 0001 002c 0017 0017 0001 002c 0017 0017 0001 002c 0017 0017 0001 002c 0017 0017 0001 002c 0017 0017 0001 002c 0017 0017 0001 002c 0017 0017 0017 0017 0001 002c 0017 0017 0001 002c 0017 0017 0017 0017 0017 0017 0017 0017 0017 0017 0017 0017 0001 002c 0017 0017 0017 0017 0017 0017 0001 002c 0017 0017 0001 002c 0017 0017 0001 002c 0017 0017 0001 002c 0017 0017 0001 002c

31

Code IR | Pronto Hex code (continued)
Menu | 0000 0066 0000 006b 0168 00b3 0017 0017 0017 0017 0017 0017 0017 0017 0017 0017 0017 0017 0017 0017 0017 0017 0017 0017 0001 002c 0017 0017 0001 002c 0017 0017 0001 002c 0017 0017 0001 002c 0017 0017 0001 002c 0017 0017 0001 002c 0017 0017 0001 002c 0017 0017 0001 002c 0017 0017 0017 0017 0017 0017 0001 002c 0017 0017 0017 0017 0001 002c 0017 0017 0017 0017 0001 002c 0017 0017 0017 0017 0001 002c 0017 0017 0001 002c 0017 0017 0017 0017 0001 002c 0017 0017 0017 0017 0001 002c 0017 0017 0017 0017 0001 002c 0017 0017 0001 002c
Return | 0000 0066 0000 006b 0168 00b3 0017 0017 0017 0017 0017 0017 0017 0017 0017 0017 0017 0017 0017 0017 0017 0017 0017 0017 0001 002c 0017 0017 0001 002c 0017 0017 0001 002c 0017 0017 0001 002c 0017 0017 0001 002c 0017 0017 0001 002c 0017 0017 0001 002c 0017 0017 0001 002c 0017 0017 0001 002c 0017 0017 0017 0017 0001 002c 0017 0017 0001 002c 0017 0017 0017 0017 0017 0017 0001 002c 0017 0017 0017 0017 0017 0017 0001 002c 0017 0017 0017 0017 0017 0017 0001 002c 0017 0017 0001 002c 0017 0017 0017 0017 0001 002c 0017 0017 0001 002c

Clear

A < C | 0000 0066 0000 006b 0168 00b3 0017 0017 0017 0017 0017 0017 0017 0017 0017 0017 0017 0017 0017 0017 0017 0017 0017 0017 0001 002c 0017 0017 0001 002c 0017 0017 0001 002c 0017 0017 0001 002c 0017 0017 0001 002c 0017 0017 0001 002c 0017 0017 0001 002c 0017 0017 0001 002c 0017 0017 0017 0017 0001 002c 0017 0017 0001 002c 0017 0017 0001 002c 0017 0017 0017 0017 0017 0017 0017 0017 0017 0017 0001 002c 0017 0017 0017 0017 0017 0017 0017 0017 0001 002c 0017 0017 0001 002c 0017 0017 0001 002c 0017 0017 0001 002c 0017 0017 0001 002c
Beep On-Off | 0000 0066 0000 006b 0168 00b3 0017 0017 0017 0017 0017 0017 0017 0017 0017 0017 0017 0017 0017 0017 0017 0017 0017 0017 0001 002c 0017 0017 0001 002c 0017 0017 0001 002c 0017 0017 0001 002c 0017 0017 0001 002c 0017 0017 0001 002c 0017 0017 0001 002c 0017 0017 0001 002c 0017 0017 0017 0017 0001 002c 0017 0017 0017 0017 0001 002c 0017 0017 0001 002c 0017 0017 0017 0017 0017 0017 0017 0017 0001 002c 0017 0017 0017 0017 0001 002c 0017 0017 0017 0017 0017 0017 0001 002c 0017 0017 0001 002c 0017 0017 0001 002c 0017 0017 0001 002c

32

Command | Description | Code (HEX) | Response (on success) | Response (on error)
Send '0' | Sends '0' key | [0x30] | [ACK] | [NACK]
Send '1' | Sends '1' key | [0x31] | [ACK] | [NACK]
Send '2' | Sends '2' key | [0x32] | [ACK] | [NACK]
Send '3' | Sends '3' key | [0x33] | [ACK] | [NACK]
Send '4' | Sends '4' key | [0x34] | [ACK] | [NACK]
Send '5' | Sends '5' key | [0x35] | [ACK] | [NACK]
Send '6' | Sends '6' key | [0x36] | [ACK] | [NACK]
Send '7' | Sends '7' key | [0x37] | [ACK] | [NACK]
Send '8' | Sends '8' key | [0x38] | [ACK] | [NACK]
Send '9' | Sends '9' key | [0x39] | [ACK] | [NACK]
Send [+/] | Sends [+/] key | [0x3A] | [ACK] | [NACK]
Send [.] | Sends [.] (dot) key | [0x3B] | [ACK] | [NACK]
Send [UP or +] | Sends [UP or +] key | [0x3C] | [ACK] | [NACK]
Send [Down or ] | Sends [Down or ] key | [0x3D] | [ACK] | [NACK]
Send [Right or *] | Sends [Right or *] key | [0x3E] | [ACK] | [NACK]
Send [Left or /] | Sends [Left or /] key | [0x3F] | [ACK] | [NACK]
Send [ENTER] | Sends [ENTER] key | [0x40] | [ACK] | [NACK]
Send [MENU] | Sends [MENU] key | [0x41] | [ACK] | [NACK]
Send [RETURN] | Sends [RETURN] key | [0x42] | [ACK] | [NACK]
Send [CLEAR] | Sends [CLEAR] key | [0x43] | [ACK] | [NACK]
Send [A<-C] | Sends [A<-C] key | [0x44] | [ACK] | [NACK]
Send [BEEP/OFF] | Sends [BEEP ON/OFF] key | [0x45] | [ACK] | [NACK]

## UART for IoT (Summary)

Keys commands

33

Command | Description | Code (HEX) | Response (on success) | Response (on error)
AUTHOR E-MAIL | Sends author email | [0x6C] | [ACK] [AUTHOR E-MAIL] | [NACK]
AUTHOR NAME | Sends author name | [0x68] | [ACK] [AUTHOR NAME] | [NACK]
AUTHOR USER | Sends author user | [0x53] | [ACK] [AUTHOR USER] | [NACK]
BEEP TEST | Beep Test | [0x62] | [ACK] | [NACK]
FIRMWARE VER. | Sends the version of Firmware | [0x56] | [ACK] [FIRMWARE VER.] | [NACK]
HARDWARE VER. | Sends the version of Hardware | [0x57] | [ACK] [HARDWARE VER.] | [NACK]
READ PIN(S) | Read(s) pin(s) information | [0x70] | [ACK] [VALUE] | [NACK] [ERROR MSG]
READ SENSOR | Read(s) sensor(s) information (1) | [0x4E] [SENSOR No.] | [ACK] [VALUE] | [NACK]
RESET MCU | Reset the microcontroller | [0x7A] | [ACK] | [NACK]
WRITE PIN(S) | Write(s) pin(s) data (2) | [0x50] [VALUE] | [ACK] | [NACK] [ERROR MSG]

Hardware/Peripheral information and control

Command | Description | Code (HEX) | Response (on success) | Response (on error)
READ DATE | Sends date in ASCII format | [0x74] | [ACK] [y][y][y][y][m][m][d][d][w][w] | [NACK]
READ TIME | Send time in ASCII format | [0x69] | [ACK] [h] [h] [m] [m] [s] [s] | [NACK]
WRITE DATE | Writes date in BCD format (3) | [0x46] [y1] [y0] [m] [d] | [ACK] | [NACK] [ERROR MESSAGE]
WRITE TIME | Writes time in BCD format (3) | [0x54] [hh] [mm] [ss] | [ACK] | [NACK] [ERROR MESSAGE]

Date/Time control

(1) Where [SENSOR No.]=0x01 for reading external temperature sensor in °C or °F, [SENSOR No.]=0x02 for reading internal MCU temperature sensor in °C or °F, [SENSOR No.]=0x04 for reading B1 battery voltage (in volts) and [SENSOR No.]=0x08 for readingB2 battery voltage (in volts).
(2) Where [VALUE] = [P6P5P4P3P2P1XX], where Pn

=Pinn

(output pins) and XX are don't care bits.

(3) Year range from (1900 to 2099) => [y1][y0]=[0x1900 .. 0x2099], month range from 1 (january) to 12 (december) => [m]=[0x01 .. 0x12], day range from 1 to 31 [d]=[0x01 .. 0x31], hour range from 00 to 23 => [hh]=[0x00 .. 0x23], minutes range from (0 to 59) [mm]=[0x00 .. 0x59] and finally seconds range from 0 to 59 => [ss]=[0x00 .. 0x59]. All these values are in BCD format. Example: If you want to set date to July 6, 2015 just send the following command: [0x46][0x20][0x15][0x07][0x06].

34

Command | Description | Code (HEX) | Response (on success) | Response (on error)
READ EEPROM | Reads EEPROM memory | [0x72] [ADDR_H] [ADDR_L] | [ACK] [VALUE] | [NACK] [ERROR MSG.]
READ FLASH | Reads FLASH memory | [0x4C] [ADDR_H] [ADDR_L] | [ACK] [VALUE] | [NACK] [ERROR MSG.]
READ SRAM | Reads SRAM memory | [0x6D] [ADDR_H] [ADDR_L] | [ACK] [VALUE] | [NACK] [ERROR MSG.]
WRITE EEPROM | Writes EEPROM value | [0x52] [ADDR_H] [ADDR_L] [VALUE] | [ACK] | [NACK] [ERROR MSG.]
WRITE SRAM | Writes SRAM value | [0x4D] [ADDR_H] [ADDR_L] [VALUE] | [ACK] | [NACK] [ERROR MSG.]

Memory read/write access

Command | Description | Code (HEX) | Response (on success) | Response (on error)
I 2C RECEIVE | Receive I 2C data | [0x76] | [ACK] [DATA] | [NACK] [ERROR MSG.]
I 2C SEND START | Sends START command to I 2C | [0x73] | [ACK] | [NACK] [ERROR MSG.]
I 2C SEND STOP | Sends STOP command to I 2C | [0x6F] | [ACK] | [NACK] [ERROR MSG.]
I 2C TRANSMIT | Transmits I 2C data | [0x64] [VALUE] | [ACK] | [NACK] [ERROR MSG.]

I2C communication access

35

Command | Description | Code (HEX) | Response (on success) | Response (on error)
ENTER LCD MODE | Enter LCD mode | [0x63] | [ACK] [MSG.] | [NACK] [ERROR MSG.]
LCD CLEAR LINE | Clear line in LCD | [0x49] [LINE] | [ACK] | [NACK] [ERROR MSG.]
LCD CLEAR SCREEN | Clear LCD screen | [0x6E] | [ACK] | [NACK] [ERROR MSG.]
LCD CONTROL | Control LCD (4) | [0x75] [CONTROL] | [ACK] | [NACK] [ERROR MSG.]
LCD DATA | Sends a data to LCD (4) | [0x61] [DATA] | [ACK] | [NACK] [ERROR MSG.]
EXIT LCD MODE | Exits LCD mode | [0x4F] | [ACK] | [NACK] [ERROR MSG.]
LCD RETURN HOME | Return HOME | [0x48] | [ACK] | [NACK] [ERROR MSG.]
LCD SET CURSOR | Set cursor at position [cccccrrr] (5) | [0x55] [cccccrrr] | [ACK] | [NACK] [ERROR MSG.]

LCD control

(4) Refer to HD 44780 (LCD panel) datasheet for data/control for complete details.

(5)

[0x55][cccccrrr]Where [rrr] are rows from [1 to 4], and [ccccc] are columns from [1 to 20]. Example. If you want set cursor at (2, 15) just send command: the following command: [0x55][0x7A] where, [0x7A]=[0b01111010].

36

Bug fixes (firmware)

Bug # | Description | Fixed date
1 | READ SENSOR must be 2 digit | 08/26/2015
2 | READ SENSOR always returns NACK even when data success | 08/26/2015
3 | WRITE DATE is not working | 08/26/2015
4 | WRITE TIME is not working and crashes data | 08/26/2015
5 | RECEIVE DATA sometimes halts microcontroller | 08/26/2015
6 | Could not read SRAM when access is allowed | 07/23/2015
7 | Could not read FLASH when access is allowed | 07/23/2015
8 | Could not load DWORD value from FLASH | 08/26/2014
9 | Could not load byte from FLASH with index | 08/26/2014
10 | Function BCD_to_uint8 returns less than zero | 08/27/2015
11 | Wrong value in function get_month_day | 10/01/2015
12 | else statement is not compiling. Error in avrgcc | 10/02/2015
13 | Turnon/off setup error when programming | 05/14/2015
14 | Error when checking user password | 07/27/2015
15 | (SECURUTY) must digest user password before write | 07/12/2015
16 | Error in SetCursor function | 07/28/2015
17 | (SECURITY) error at function is_null_pass | 07/18/2015
18 | Error in function UART_println | 08/26/2015
19 | Error in check_uart_error. Old data should be flushed | 08/28/2015

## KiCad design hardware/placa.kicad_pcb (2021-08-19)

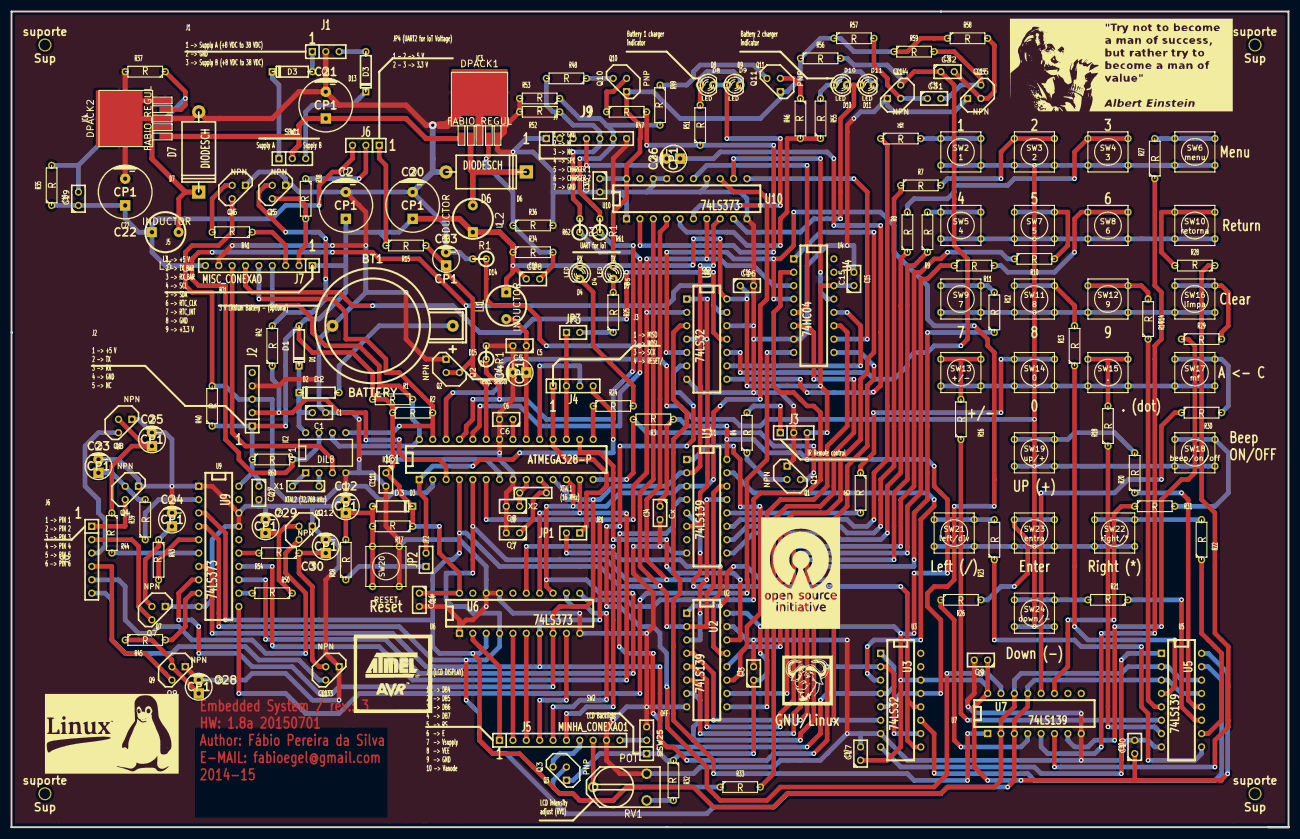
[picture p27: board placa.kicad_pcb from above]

Board: 2 copper layers, 242.6 x 154.9 mm, 188 parts (0 on the bottom side), 165 nets.

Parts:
BT1: BATTERY; CR2032H
C1, C3, C5, C6, C7, C8, C9, C10, C11, C14, C15, C16, C17, C18, C19, C27, C31, C32, C33: C; C1
C2, C21: CP1; CP_10x16mm
C4, C12, C13, C23, C24, C25, C26, C28, C29, C30: CP1; CP_5x11mm
C20, C22: CP1; CP_10x21mm
Cx: V***; C1
D1, D2, D3: DIODE; D3
D3#2: D12; D3
D3#3: D13; D3
D4, D5, D8, D9, D10, D11: LED; LED-3MM
D6, D7: DIODESCH; D6
DPACK1, DPACK2: FABIO_REGUL; DPAK5
IC1: ATMEGA328-P; DIP-28__300
J1: MINHA_CONEXAO7; SIL-3
J2: MINHA_CONEXAO5; SIL-5
J3: MINHA_CONEXAO6; SIL-3
J4: MINHA_CONEXAO4; SIL-4
J5: MINHA_CONEXAO1; SIL-10
J6: FABIO_CON_3; SIL-3
J7: MISC_CONEXAO; SIL-9
J8: MINHA_CONEXAO2; SIL-6
J9: MINHA_CONEXAO3; SIL-7
JP1, JP2, JP3: JUMPER; SIL-2
L1, L2, L3: INDUCTOR; INDUCTOR_V
P1: DIL8; DIP-8__300
Q1, Q2, Q4, Q5, Q6, Q7, Q8, Q9, Q12, Q13, Q14, Q15: NPN; TO92
Q3, Q10, Q11: PNP; TO92
R1, R2, R3, R4, R5, R6, R7, R8, R9, R10, R11, R12, R13, R14, R15, R16, R17, R18, R19, R20, R21, R22, R23, R24, R25, R26, R27, R28, R29, R30, R31, R32, R33, R34, R35, R36, R37, R38, R39, R40, R41, R42, R43, R44, R45, R46, R47, R48, R49, R50, R51, R52, R53, R54, R55, R56, R57, R58, R59, R60: R; R3
R1#2: R61; R1
R1#3: R62; R1
R1#4: D14; R1
R1#5: D15; R1
RV1: POT; RV2X4
SW1: SWITCH_INV; MICROSWITCH_SPST
SW2: 1; SW_PUSH_SMALL
SW3: 2; SW_PUSH_SMALL
SW4: 3; SW_PUSH_SMALL
SW5: 4; SW_PUSH_SMALL
SW6: menu; SW_PUSH_SMALL
SW7: 5; SW_PUSH_SMALL
SW8: 6; SW_PUSH_SMALL
SW9: 7; SW_PUSH_SMALL
SW10: retorna; SW_PUSH_SMALL
SW11: 8; SW_PUSH_SMALL
SW12: 9; SW_PUSH_SMALL
SW13: +/-; SW_PUSH_SMALL
SW14: 0; SW_PUSH_SMALL
SW15: .; SW_PUSH_SMALL
SW16: limpa; SW_PUSH_SMALL
SW17: mf; SW_PUSH_SMALL
SW18: beep/on/off; SW_PUSH_SMALL
SW19: up/+; SW_PUSH_SMALL
SW20: RESET; SW_PUSH_SMALL
SW21: left/div; SW_PUSH_SMALL
SW22: right/*; SW_PUSH_SMALL
SW23: entra; SW_PUSH_SMALL
SW24: down/-; SW_PUSH_SMALL
SW25: SWITCH_INVe; MICROSWITCH_SPST
U1, U2, U5, U7: 74LS139; DIP-16__300
U3: 74LS32; DIP-16__300
U4: 74HC04; DIP-16__300
U6, U9, U10: 74LS373; DIP-20__300
U8: 74LS32; DIP-14__300
X1, X2: CRYSTAL; C2
suporte: Sup; suporte
suporte#2, suporte#3, suporte#4: Sup; suporte

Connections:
+3.3V: C19.1, C22.1, J6.3, J7.9, L3.1, R35.1
+24V: C21.1, DPACK1.1, DPACK2.1, SW1.2
/00: IC1.4, U1.14, U2.2, U5.2, U5.14, U6.3, U7.2, U7.14, U9.3, U10.3
/01: IC1.5, U1.13, U2.3, U5.3, U5.13, U6.4, U7.3, U7.13, U9.4, U10.4
/02: IC1.6, U3.2, U3.10, U4.3, U6.7, U8.2, U9.7, U10.7
/03: IC1.11, U1.2, U6.8, U9.8, U10.8
/04: IC1.12, U1.3, U6.13, U9.13, U10.13
/05: IC1.13, U6.14, U9.14
/a1: IC1.24, R1#3.1, R1#4.1
/a2: IC1.25, R1#2.1, R1#5.1
GND: BT1.2, C1.2, C2.2, C3.2, C4.2, C5.2, C6.2, C7.2, C8.2, C9.2, C10.2, C11.2, C12.2, C13.2, C14.2, C15.2, C16.2, C17.2, C20.2, C21.2, C22.2, C23.2, C24.2, C25.2, C27.2, C28.2, C29.2, C30.2, C33.2, Cx.2, D6.1, D7.1, DPACK1.3, DPACK1.5, DPACK2.3, DPACK2.5, IC1.8, IC1.22, J1.2, J2.4, J3.2, J5.9, J7.8, J9.1, J9.7, P1.4, Q1.1, Q2.1, Q4.1, Q5.1, Q6.1, Q7.1, Q8.1, Q9.1, Q12.1, Q13.1, Q14.1, Q15.1, R1#4.2, R1#5.2, R36.2, R37.2, R52.2, R53.2, RV1.3, SW20.2, SW25.3, U1.8, U2.8, U2.15, U3.7, U4.7, U5.8, U6.1, U6.10, U6.17, U6.18, U7.8, U8.7, U8.12, U9.1, U9.10, U9.17, U9.18, U10.1, U10.10, U10.14, U10.17, U10.18
unnamed: P1.1, X1.2
unnamed: P1.2, X1.1
unnamed: J8.2, Q7.3
unnamed: D8.1, D9.2, R51.2
unnamed: D8.2, D9.1, U10.6
unnamed: D10.1, D11.2, R55.2
unnamed: R47.2, R51.1, U10.2
unnamed: C26.2, J9.4
unnamed: C26.1, U8.8
unnamed: BT1.1, D2.1
unnamed: Q1.2, R4.1
unnamed: J3.1, R4.2
unnamed: D3#3.2, SW1.3
unnamed: D3#2.2, SW1.1
unnamed: R54.2, U9.15
unnamed: J8.1, Q4.3
unnamed: J8.4, Q9.3
unnamed: J8.6, Q13.3
unnamed: R39.1, U9.2
unnamed: R43.2, U9.5
unnamed: Q3.2, R33.1
unnamed: Q10.3, R48.1
unnamed: Q11.3, R49.1
unnamed: Q10.2, R47.1
unnamed: Q11.2, R46.1
unnamed: J8.5, Q12.3
unnamed: J8.3, Q8.3
unnamed: C32.2, Q15.2, R58.2
unnamed: J5.10, SW25.2
unnamed: J5.8, RV1.2
unnamed: J5.7, Q3.3
unnamed: C24.1, Q7.2, R43.1
unnamed: D4.2, R24.2
unnamed: D5.2, R25.2
unnamed: J6.2, R38.1
unnamed: IC1.14, Q1.3, R3.2
unnamed: J7.3, R41.1
unnamed: C23.1, Q4.2, R39.2
unnamed: C25.1, Q8.2, R44.1
unnamed: C28.1, Q9.2, R45.1
unnamed: C29.1, Q12.2, R50.1
unnamed: C30.1, Q13.2, R54.1
unnamed: C18.2, DPACK1.4, R34.2, R36.1
unnamed: D6.2, DPACK1.2, L2.2
unnamed: J7.2, Q5.3, R38.2
unnamed: Q6.2, R41.2
unnamed: Q5.2, R42.2
unnamed: JP3.2, R25.1
unnamed: R8.2, SW4.1
unnamed: R10.2, SW7.1
unnamed: R14.2, SW12.1
unnamed: R5.1, SW14.1
unnamed: R20.2, SW19.1
unnamed: R23.2, SW21.1
unnamed: R22.2, SW22.1
unnamed: R26.2, SW23.1
unnamed: U3.8, U5.1
unnamed: U3.11, U5.15
unnamed: IC1.1, J4.4, JP2.2
unnamed: JP2.1, R19.1
unnamed: R6.2, SW2.1
unnamed: R7.2, SW3.1
unnamed: R28.2, SW10.1
unnamed: R30.2, SW17.1
unnamed: R9.2, SW5.1
unnamed: R12.2, SW9.1
unnamed: R16.2, SW13.1
unnamed: U1.1, U2.11
unnamed: U2.10, U4.9
unnamed: U2.9, U4.11
unnamed: C6.1, IC1.21
unnamed: IC1.19, J4.3
unnamed: IC1.16, U2.14
unnamed: C13.1, IC1.23, Q2.2, Q2.3, R15.2
unnamed: JP1.2, U2.13
unnamed: R5.2, U1.12
unnamed: R6.1, U1.11
unnamed: R7.1, U1.10
unnamed: R8.1, U1.9
unnamed: R9.1, U2.4
unnamed: C8.1, IC1.9, X2.1
unnamed: U4.2, U6.11
unnamed: J5.4, U6.9
unnamed: J5.3, U6.6
unnamed: J5.2, U6.5
unnamed: J5.1, U6.2
unnamed: U1.6, U8.1, U8.4
unnamed: U7.15, U8.6
unnamed: C32.1, Q14.3, R56.2, U8.10
unnamed: J5.6, U6.15
unnamed: J5.5, U6.12
unnamed: D10.2, D11.1, U10.9
unnamed: R32.2, RV1.1
unnamed: R50.2, U9.12
unnamed: U4.8, U9.11
unnamed: R44.2, U9.6
unnamed: R26.1, U7.4
unnamed: U1.15, U3.3
unnamed: U2.1, U3.6
unnamed: R12.1, U2.7
unnamed: R11.2, SW8.1
unnamed: R11.1, U2.6
unnamed: R10.1, U2.5
unnamed: R16.1, U5.6
unnamed: R13.2, SW11.1
unnamed: R13.1, U5.4
unnamed: R18.1, U5.7
unnamed: R14.1, U5.5
unnamed: R22.1, U5.10
unnamed: R20.1, U5.12
unnamed: R23.1, U5.9
unnamed: R21.2, SW24.1
unnamed: R21.1, U5.11
unnamed: R29.2, SW16.1
unnamed: R29.1, U7.7
unnamed: R28.1, U7.6
unnamed: R31.2, SW18.1
unnamed: R31.1, U7.11
unnamed: R30.1, U7.12
unnamed: R27.2, SW6.1
unnamed: R27.1, U7.5
unnamed: R33.2, U4.6
unnamed: U4.5, U10.15
unnamed: U4.13, U10.12
unnamed: U4.12, U8.9
unnamed: U1.5, U3.9, U3.12
unnamed: U2.12, U4.1
unnamed: U4.10, U10.11
unnamed: C12.1, D3.1, R17.2, R19.2, SW20.1
unnamed: R18.2, SW15.1
unnamed: U7.1, U8.3
unnamed: U1.4, U3.1, U3.4
unnamed: R45.2, U9.9
unnamed: C19.2, DPACK2.4, R35.2, R37.1
unnamed: D7.2, DPACK2.2, L3.2
unnamed: C1.1, D1.2, D2.2, P1.8
unnamed: C31.2, Q15.3, R59.2
unnamed: C31.1, Q14.2, R57.2
unnamed: IC1.18, J4.1, JP1.1
unnamed: R46.2, R55.1, U10.5
unnamed: C4.1, C5.1, IC1.20, L1.2
unnamed: C7.1, IC1.10, X2.2
unnamed: U3.5, U3.13, U4.4, U8.5
unnamed: IC1.26, SW2.2, SW3.2, SW4.2, SW5.2, SW6.2, SW7.2, SW8.2, SW9.2, SW10.2, SW11.2, SW12.2, SW13.2, SW14.2, SW15.2, SW16.2, SW17.2, SW18.2, SW19.2, SW21.2, SW22.2, SW23.2, SW24.2
RTC_CLK: J7.6, U8.11
RTC_CLK_OPEN_DRAIN: P1.7, R60.2, U8.13
RTC_INT_OPEN_DRAIN: J7.7, P1.3
RX: IC1.2, J2.3, Q6.3, R40.2
SCL: IC1.28, J7.4, P1.6, R1.2
SDA: IC1.27, J7.5, P1.5, R2.2
TO_LED_RX: IC1.15, R24.1
TO_LED_TX: IC1.17, J4.2, JP3.1
TX: IC1.3, J2.2, R42.1
VCC: C2.1, C3.1, C9.1, C10.1, C11.1, C14.1, C15.1, C16.1, C17.1, C18.1, C20.1, C27.1, C33.1, Cx.1, D1.1, D3.2, D4.1, D5.1, IC1.7, J2.1, J3.3, J6.1, J7.1, L1.1, L2.1, Q3.1, Q10.1, Q11.1, R1.1, R2.1, R3.1, R15.1, R17.1, R32.1, R34.1, R40.1, R56.1, R57.1, R58.1, R59.1, R60.1, SW25.1, U1.16, U2.16, U3.14, U4.14, U5.16, U6.20, U7.16, U8.14, U9.20, U10.20

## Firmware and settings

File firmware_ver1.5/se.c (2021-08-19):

/*
 * se.c
 * This file is part of se.fw
 *
 * 2015 - Fábio Pereira da Silva
 * LICENSE: MIT
 */

#define F_CPU 16000000

#include <avr/io.h>
#include <util/delay.h>
#include "display_ver23.h"
#include "rtc.h"
//#include "timer_event.h"
//#include "dow.h"
#include <stdlib.h> 
#include <math.h>
#include <avr/interrupt.h>
#include <stdint.h>
#include <avr/pgmspace.h>
#include "pgmstrings.h"
#include "uartcmd.h"
//#include "sha1b.h"
#include "mhd.h"
//#define MAX 53
#define MAX 0x19 // 25
//#define MAX 0x32

#define TIMER0_1440_US 0xA6+0x010
//#define TIMER0_1200_US 0xBA
#define TIMER_4000_US 0x00

#define TIMER1_ENABLE 0x80
#define TIMER1_DISABLE ~(TIMER1_ENABLE)

#define SELECT_LCD 0x00
#define SELECT_KBD_OR_NONE 0x04
#define SELECT_PINOS 0x10 
#define SELECT_AUX_REG 0x14

#define CHARGER1_OFF 0x04
#define CHARGER2_OFF 0x08
#define SPK_ON 0x40
#define LCD_ON 0x80

#define PINO1 0x04
#define PINO2 0x08
#define PINO3 0x10
#define PINO4 0x20
#define PINO5 0x40
#define PINO6 0x80

#define IS_KBD_KEY_PRESSED 0x01
#define IS_MENU 0x80
#define MENU_KEY 0x41
#define RETURN_KEY 0x42
#define PLUS_MINUS_KEY 0x3A
#define DOT_KEY 0x3B
#define UP_PLUS_KEY 0x3C
#define DOWN_MINUS_KEY 0x3D
#define RIGHT_MULTIPLY_KEY 0x3E
#define LEFT_DIVIDE_KEY 0x3F
#define ENTER_KEY 0x40
#define CLEAR_KEY 0x43
#define MF_KEY 0x44
#define BEEP_ON_OFF 0x45
#define BEEP_ENABLE 0x40
/////////
#define ABOUT_MENU 0xB0
#define CALCULATOR_MENU 0xA8
#define BASIC_CALC_MENU 0xA9
#define SCIENTIFIC_MENU 0xAA
#define DATE_TIME_MENU 0x88
#define DATE_TIME_ADJUST 0x89
#define DATE_TIME_WEEK_DAY 0x8A
#define ALARM_SETUP 0x8B
#define SENSOR_MENU 0xA0
#define OTHER_MENU 0x98
#define OTHER_MENU_LANGUAGE 0x99

#define OTHER_MENU_TEMP_MEASUREMENT 0xF0
#define OTHER_MENU_UART_FOR_IOT 0xF1
#define OTHER_MENU_SECURITY 0xF2
#define OTHER_MENU_SET_PASSWORD 0xF3
#define OTHER_MENU_CONFIGURE_PORT_UART 0xF4
#define OTHER_MENU_CONFIGURE_SPEED_UART 0xF5
#define OTHER_MENU_CONFIGURE_PARITY_UART 0xF6
#define OTHER_MENU_CONFIGURE_DEF 0xF7
#define OTHER_MENU_CONFIGURE_UART2X 0xF8
#define OTHER_MENU_CONFIGURE_UART_SECURITY 0xF9
#define OTHER_MENU_CONFIGURE_UART_SEC_PERM 0xFA
#define OTHER_MENU_CONFIGURE_DEF_SECURITY 0xFB

#define OTHER_MENU_UART_FOR_IOT_PASSWD 0xFC
#define OTHER_MENU_CONFIGURE_UART 0xFD
#define MIN_UART_LOCK_INTERVAL OTHER_MENU_UART_FOR_IOT
#define MAX_UART_LOCK_INTERVAL OTHER_MENU_CONFIGURE_UART

/////
#define PINO_MENU 0xB8
#define PINO_MENU_P1 0xB9
#define PINO_MENU_P2 0xBA
#define PINO_MENU_P3 0xBB
#define PINO_MENU_P4 0xBC
#define PINO_MENU_P5 0xBD
#define PINO_MENU_P6 0xBE
/////////////////////////
// about sensors input //
/////////////////////////
//#define TEMP1_SENSOR (1<<REFS0)
#define TEMP1_SENSOR ((1<<REFS1)|(1<<REFS0))
#define TEMP2_SENSOR ((1<<REFS1)|(1<<REFS0)|(1<<MUX3))
#define B1_SENSOR ((1<<REFS1)|(1<<REFS0)|(1<<MUX0))
#define B2_SENSOR ((1<<REFS1)|(1<<REFS0)|(1<<MUX1))

// end sensor input

//////////////////
// LED's pilots //
//////////////////
#define B1_LED_SIGNAL 0x10
#define B2_LED_SIGNAL 0x20
// END LED PILOTS

static unsigned char pseudo_latch_pinos, pseudo_latch_aux;
static double t1, t2, b1, b2;//, d_tmp_var;

static const double charged_voltage=1.415, uncharged_voltage=1.35, high_voltage=1.55, low_voltage=0.5;
static const double inv_100_charged_voltage= 70.67137809;//69.444444;// 100/charged_voltage=1.44
static const double pi_inv_180=0.0174532925199433;
static const double deg_inv_pi=57.295779513082321;

///////////////////////////
// EEPROM memory address //
///////////////////////////
#define PINO1_OFFSET_ADDR 0x02
#define PINO2_OFFSET_ADDR 0x15
#define PINO3_OFFSET_ADDR 0x28
#define PINO4_OFFSET_ADDR 0x3B
#define PINO5_OFFSET_ADDR 0x4E
#define PINO6_OFFSET_ADDR 0x61

// END EEPROM memory address

/*
	UART Serial communication for IoT

*/
//#define BAUD 9600                           // define baud
//#define UBRR ((F_CPU)/(BAUD*16UL)-1)

#define UART_TIME_OUT 0x80 // the bit 8 of uart_cmd_count_max are used to flag timeout
#define UART_READY_STREAM_DATA 0x40 // the uart bit 7 is flag to be ready to receive stream data
#define UART_COMMAND_MAX_ENTRY 0x09
//static char uart_command[UART_COMMAND_MAX_ENTRY]={0x00};
static unsigned char uart_command[UART_COMMAND_MAX_ENTRY]={0x00};
static unsigned char uart_cmd_count, uart_cmd_count_max=0;

// end UART for IoT
//////////////////
// PINS MONITOR //
//////////////////
static struct PINOS_t
{
	// command b7:b3--> reserved | b2:b0-->command
	unsigned char command,hh1,mm1,hh2,mm2, hh3,mm3,ss3,hh4,mm4,ss4,hh5,mm5,ss5, opbat1, opbat2, gpv;
	// gpv = general purpose var
	unsigned int countdown1, countdown2, countdown3;
	signed char d, e;

}pino1,pino2,pino3,pino4,pino5,pino6;

// END PINS MONITOR

#define MAX_INPUT 0x11


double toFarenheit(double *address)
{
	asm
	(
		"ld r22, Y" "\n\t"
		"ldd r23, Y+1" "\n\t"
		"ldd r24, Y+2" "\n\t"
		"ldd r25, Y+3" "\n\t"
		"ldi r18, 0x66" "\n\t"
		"ldi r19, 0x66" "\n\t"
		"ldi r20, 0xE6" "\n\t"
		"ldi r21, 0x3F" "\n\t"
		"call __mulsf3" "\n\t"
		"ldi r18, 0x00" "\n\t"
		"ldi r19, 0x00" "\n\t"
		"ldi r20, 0x00" "\n\t"
		"ldi r21, 0x42" "\n\t"
		"call __addsf3" "\n\t"
		//"ret" "\n\t"
	:
	:"y"(address)
	);
}

#define to_uint_16(high, low) \
(__extension__					\
	(							\
		{						\
			unsigned char __high=(unsigned char)(high); \
			unsigned char __low=(unsigned char)(low);	\
			uint16_t __result_a;						\
			__asm__										\
			(											\
				"mov %B0, %2" "\n\t"					\
				"mov %A0, %1" "\n\t"					\
				:"=r"(__result_a)						\
				:"r"(__low),"r"(__high)					\
			);											\
			__result_a;									\
		}												\
	)													\
)
#define compare_int_16_ovf(value) 						\
(__extension__											\
	(													\
		{												\
			uint32_t __value=(uint32_t)(value); 		\
			uint8_t __result_a;							\
			__asm__										\
			(											\
				"cli" "\n\t"							\
				"ldi r24, 0x01" "\n\t"					\
				"cp %A1, r1" "\n\t"						\
				"cpc %B1, r1" "\n\t"					\
				"cpc %C1, r24" "\n\t"					\
				"cpc %D1, r1" "\n\t"					\
				"brcc OVF_SAIR" "\n\t"					\
				"ldi r24, 0x00" "\n\t"					\
			"OVF_SAIR:" "\n\t"							\
				"sei" "\n\t"							\
				:"=r"(__result_a)						\
				:"r"(__value)							\
			);											\
			__result_a;									\
		}												\
	)													\
)
#define hi_uint_16(value_d)								\
(__extension__											\
	(													\
		{												\
			uint32_t __value_d=(uint32_t)(value_d);		\
			uint8_t __result_d;							\
			__asm__										\
			(											\
				"mov %0, %B1" "\n\t"					\
			:"=r"(__result_d)							\
			:"r"(__value_d)								\
			);											\
			__result_d;									\
		}												\
	)													\
)

static char input[MAX_INPUT];
static unsigned char pos_input=0;

struct DT_t
{
	char year[5], month[3], day[3], hh[3], mm[3], ss[3];

}DT;

// END INPUT METHOD
extern unsigned char temporizador=0x00;
//static unsigned char code[MAX]={0};
static unsigned char n,n2,p;//temporizador=0;
static char conv[13];
//static unsigned long key;
static uint32_t key;
static unsigned char cr_start=0;
//static unsigned char cr_timer=0;
static unsigned char code_cr=0x00;;//=0xff; // valor inicial (nenhum -> 0xff);
static unsigned char tmp_gpr; // temporary general purpose;

//static uint32_t scan_cr_timeout=0x0000;

/////////////////////////
// variables for MENU //
///////////////////////
static unsigned char menu=0x00;

///////////////////////////////////
// TIME VARIABLES AND CONSTANTS //
/////////////////////////////////

static unsigned char hours, minutes;//, seconds; // current time
static unsigned char hoursA, minutesA; // Alarm variables

// END TIME VARIABLES AND CONSTANTS

//////////////////////////////////////////
// BASICS CALC VARIABLES AND CONSTANTS //
////////////////////////////////////////

#define BAS_CALC_DIGIT 10
static double A, B, C;
static char bas_calc_op;
static unsigned char pos_bas_calc, bas_calc_status=0;
static char bas_calc_char[BAS_CALC_DIGIT];
 

// END BASIC CALC AND CONSTANTS

////////////////////////////////////////
// SCIENTIFC CONSTANTS AND VARIABLES //
//////////////////////////////////////

// variable A is used as X in scientific calculator
// variable bas_calc_char is used in scientific_calculator
//static char function_name[10];
static char function_name[9];
static unsigned char function_name_op=0;

// END SCIENTIFC CONSTANTS AND VARIABLES

////////////////////////////////
// BEGIN BILINGUAL INTERFACE //
//////////////////////////////

static char language;

// END BILINGUAL INTERFACE

///////////////////////
// BEGIN PROTOTYPES //
/////////////////////

void show_menu_calculator();
void prepare_lcd();
void clean_UART_STREAM();
void beepAlarm();
unsigned char EEPROM_read(unsigned int uiAddress);
//void EEPROM_write(unsigned int uiAddress, unsigned char ucData);
unsigned char valid_time(unsigned char hh, unsigned char mm, unsigned char ss);
unsigned char is_BCD(unsigned char value);
unsigned char BCD_to_uint8(unsigned char valuea);
unsigned char valid_date(unsigned char day, unsigned char month, unsigned int year);
int getDay(int y, int m, int d);
void set_none();
void exit_menu();
void set_latch_pinos();

// end prototypes

extern void EEPROM_write(unsigned int uiAddress, unsigned char ucData) asm ("asm_EEPROM_WRITE");
extern unsigned char is_BCD(unsigned char value) asm ("asm_IS_BCD");
extern void turn_on_timer_2(unsigned char time2) asm ("asm_TURN_ON_TIMER_2");
extern unsigned char EEPROM_read(unsigned int uiAddress) asm ("asm_EEPROM_READ");
extern void fill_null_char(const uint16_t address, unsigned char size);
void show_other_menu();

unsigned char read_write_temporizador(unsigned char value_k)
{
	asm volatile
	(
		//"push r16" "\n\t"
		"lds r0, 0x00B1" "\n\t" // save state of timer 2
		"sts 0x00B1, r1" "\n\t" // pause timer2 (if enabled)
		"sts 0x0081, r1" "\n\t" // pause timer 1
		"st X, %0" "\n\t"
		"ldi r26, 0x05" "\n\t"
		"sts 0x0081, r26" "\n\t" // continue timer 1
		"sts 0x00B1, r0" "\n\t" // continue timer 2 (if enabled)
		//"pop r16"
	:"=r"(value_k)
	:"x"(&temporizador)
	);
	return value_k;
}

void turn_off_timer0()
{
	TCCR0B=0x00;
	TIMSK0=0x00;
	TCNT0=0x00;
}
void turn_on_timer0(unsigned char start)
{
	TCCR0B=0x00;
	TCNT0=start;
	TIMSK0=(1<<TOIE0);
	TCCR0B=(1<<CS02); // prescale by fs/256 (counter 0)
}

void turn_on_timer_2(unsigned char time2)
{

	TCCR1B=0x00;
	asm volatile
	(
		"ld r25, X" "\n\t"
		"or r25, %1" "\n\t"
		"st X, r25" "\n\t"
		"ldi %1, 0x01" "\n\t"
		"sts 0x0070, %1" "\n\t" // TIMSK2 interrupt enabled
		"ldi %1, 0x07" "\n\t" // fs/1024 timer 2 on
		"sts 0x00B1, %1" "\n\t"
	://"+x"(&temporizador)
	:"x"(&temporizador), "r"(time2)
	);
	TCCR1B=(1<<CS12)|(1<<CS10);
}

unsigned char validate_uart_access(uint16_t address, unsigned char what_c)
{

	asm volatile
	(
		"call asm_EEPROM_READ" "\n\t"
		"and %0, %1" "\n\t"
		"brne validate_uart_access_SAIR" "\n\t"
		"ldi r24, 0x15" "\n\t" //  NACK
		"call asm_UART_TRANSMIT" "\n\t"
		"ld r24, X" "\n\t"
//		"andi r24, 0x01" "\n\t"
		"sbrc r24, 0" "\n\t"
		"adiw r30, 0x0E" "\n\t" // SizeOf(ACCESS_DENIED[0])
		"movw r24, r30" "\n\t"
		//"ldi r22, 0x01" "\n\t"
		"ldi r22, 0x03" "\n\t"
		"call asm_UART_PRINTLN" "\n\t"
		"clr r24" "\n\t" // False result
	"validate_uart_access_SAIR:" "\n\t"
	:
	:"r"(address),"r"(what_c), "x"(&language),"z"(&ACCESS_DENIED)
	);
}

//////////////////////////////
// BEGIN INTERRUPT VECTORS //
////////////////////////////

ISR(PCINT0_vect)
{

	cli();
	if (cr_start==0x01)
	{
		if (PINB & (1<<PB0))
		{
			//cli();
			PCICR=0x00;
			turn_on_timer0(TIMER0_1440_US);
			cr_start=0x10;
			key|=0x01;
			//sei();
		}
	}
	else if (cr_start==0)
	{
		if (PINB & (1<<PB0))
		{
			//cli();
			PCICR=0x00;
			turn_on_timer0(TIMER_4000_US);
			//sei();
		}
	}
}

ISR(TIMER0_OVF_vect)
{

	cli();
	if (cr_start==0x10)
	{

		key^=(PINB&(1<<PB0));
		key<<=1;

		p++;
		//cli();
		if (p<MAX)
		{
			cr_start=0x01;
			PCICR=(1<<PCIE0);
		}
		else cr_start=0x02;
		turn_off_timer0();
		//PCICR=(1<<PCIE0);
		//sei();
	}
	else if (cr_start==0)
	{
		if (PINB & (1<<PB0)) cr_start=0x04;
		else
		{
			//restart_pin_interrupt();

			//cli();
			turn_off_timer0();
			PCICR=(1<<PCIE0);
			//sei();

		}
	}
	else if (cr_start&0x04)
	{
		if (PINB & (1<<PB0))
			cr_start=0x08;
		else
		{
			//restart_pin_interrupt();
			cr_start=0x00;
			//cli();
			turn_off_timer0();
			PCICR=(1<<PCIE0);
			//sei();
		}
	}
	else if (cr_start&0x08)
	{
		if (PINB&(1<<PB0)) cr_start=0x00;
		else
		{
			cr_start=0x01;
			p=0;
			key=0x0000;
		}
		//cli();
		PCICR=(1<<PCIE0);
		turn_off_timer0();
		//sei();
	}
}

ISR(TIMER1_OVF_vect)
{
	TIMSK2=0x00;
	temporizador|=TIMER1_ENABLE;
	TIMSK2=(1<<TOIE1);
	if (uart_cmd_count_max & UART_READY_STREAM_DATA) uart_cmd_count_max|=UART_TIME_OUT;
}
ISR(TIMER2_OVF_vect)
{
	//cli();
	asm volatile (
		"sts 0x0081, r1" "\n\t" // stop timer 1 for a while
		"ld r0, X" "\n\t"
		"push r25" "\n\t"
		"mov r25, r0" "\n\t"
		"andi r25, 0x1F" "\n\t" // TIMER_EVENT
		"breq eval_timer_erro_1" "\n\t"
		"dec r25" "\n\t"
		"andi r25, 0x1F" "\n\t"
		"mov r1, r25" "\n\t"
	"eval_timer_erro_1:" "\n\t"
		"mov r25, r0" "\n\t"
		"andi r25, 0x60" "\n\t" // LOOP_EVENT
		"breq eval_timer_erro_2" "\n\t"
		"subi r25, 0x20" "\n\t" // -0x20
		"andi r25, 0x60" "\n\t" // LOOP_EVENT
		//"or r1, r25" "\n\t"
	"eval_timer_erro_2:" "\n\t"
		//"tst r1" "\n\t"
		"or r1, r25" "\n\t" // Or r25 and test at same time. I dont need tst
		"brne eval_timer_sair" "\n\t"
		"sts 0x00B1, r1" "\n\t" // HERE r1 is equal 0 (timer 2 stopped)
		"sts 0x0070, r1" "\n\t" // Interrupt (overflow disabled)
		"sts 0x00B2, r1" "\n\t" // counter =0
	"eval_timer_sair:" "\n\t"
		"mov r25, r0" "\n\t"
		"andi r25, 0x80" "\n\t"
		"or r25, r1" "\n\t"
		"st X, r25" "\n\t"
		"ldi r25, 0x05" "\n\t"
		"sts 0x0081, r25" "\n\t" // running timer 1 again
		"pop r25" "\n\t"
		//"clr r1" "\n\t" // After used r1 then set r1 to (Zero) (I don't need it in interrupt)
		//"sts X, %0" "\n\t"
	:
	:"x"(&temporizador)
	//:"y"(temporizador)
	);
}
void sub_uart_lock()
{
	UART_Transmit(UART_NACK);
	UART_println(ERR_UART_SECURUTY_LOCK ,UART_STRING_FROM_PROGRAM|SEND_EOT);
	clean_UART_STREAM();
	UART_flush();
	//code_cr=0x00; // Added 07/27/2015
	//cr_start=0x00; // Added 07/27/2015
	exit_menu(); // Added 07/24/2015
	_delay_us(600);
	beepAlarm();
		//show_other_menu();
}
static uint16_t Memory;
//static char tmp[7]; //000.00 Fixed for transmit sensors Data
static char tmp[12]; // 000.0000 FIXED (08/25/2015)
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
int main(void)
{
	uint32_t Memory_b;
	// Configurando o controle interno do MCU
	DDRD=((1<<PD7) | (1<<PD6) | (1<<PD5) | (1<<PD4) | (1<<PD3) | (1<<PD2)); //set all as output pins
	//DDRB=((1<<PB4)|(1<<PB2)); // set PB4 and PB2 as output pins
	DDRB=((1<<PB4)|(1<<PB2)|(1<<PB1)|(1<<PB3)); // set PB4 and PB2 as output pins. Now (02/26/2016) as a LED_TX and LED_RX

	DIDR0=((1<<ADC2D)|(1<<ADC1D)|(1<<ADC0D)); // disable digital input/output pins. Set them to analogical pins
	//ADMUX|=(1<<REFS0); // set Avcc with output capacitor pin.
	ADCSRA = (1<<ADEN)|(1<<ADPS2)|(1<<ADPS1)|(1<<ADPS0); // set factor to 128 for all conversions

	//PCICR=(1<<PCIE1); // ativa interrupção em todos os pinos PCI23:8
	PCICR=(1<<PCIE0); // ativa interrupção em todos os pinos PCI7:0
	//PCMSK1=(1<<PCINT8);//mascara a interrupção todos os pinos PCI23:9 menos o pino 0
	PCMSK0=(1<<PCINT0);//mascara a interrupção todos os pinos PCI7:0 menos o pino 0

	//UCSR0A=(1<<RXCIE0); // UART Tx complete interrupt enabled;

	//TCCR0B|=(1<<CS01)|(1<<CS00); // prescale by fs/64 the counter 0
	//TCCR0B|=(1<<CS02); // prescale by fs/256 (counter 0)
	//TCCR1B|=(1<<CS12)|(1<<CS10); // preescale by fs/1024 the counter 1 (16 bit)
	TCCR1B=(1<<CS12)|(1<<CS10); // preescale by fs/1024 the counter 1 (16 bit)
	//TCCR1B|=(1<<CS12); // preescale by fs/256 the counter 1 (16 bit)
	// Fim de configuração do controle interno

	// PORTC = 0b111000		
	PORTC=0x38; // Set pull-up resistor in PC3, PC4 (future use) and PC5 (future use)

	// About 2-wire:

	TWBR=0xFF; // 2-wire frequency about 7.78 kHz @ 16 MHz CPU clock
	TWSR=(1<<TWPS0);

	// End 2-wire

	set_none();
	pseudo_latch_aux=(CHARGER2_OFF|CHARGER1_OFF|B1_LED_SIGNAL|B2_LED_SIGNAL);
	pseudo_latch_aux&=~(LCD_ON); // adicionado em depuracao;

	set_latch_aux();
	pseudo_latch_pinos=0x00;
	set_latch_pinos();
	pseudo_latch_aux|=LCD_ON;
	set_latch_aux();
	_delay_ms(100);
	readLanguageEEPROM();// load a preset language (English / Portuguese)
	prepare_lcd();

	init_lcd();
	load_custom_char();
	display_on();
	clear_display();
	lcd_return_home();
	SetCursor(2,1);
	/*
	if (language)
		print_lcd2("Starting");
	else
		print_lcd2("Iniciando");
	*/
	print_lcd2_P(LANG_STARTUP[language&0x01]);
	//print_lcd2("...");
	replicate_char('.',3);
	set_none();
	n=read_from_rtc(RTC_DAYS_REG);
	n&=0x3F;
	if (n==0x00)
	{
		write_to_rtc(n, RTC_SECONDS_REG);

		write_to_rtc(n, RTC_MINUTES_REG);

		write_to_rtc(n, RTC_HOURS_REG);

		write_to_rtc(0x06, RTC_DAYS_REG);

		write_to_rtc((IS_19XX|0x07), RTC_MONTHS_CENTURY_REG);
		write_to_rtc(0x81, RTC_YEARS_REG); // fixed
		//n=getDay(1981,7,6); // Monday (1)
		write_to_rtc(0x01, RTC_WEEKDAYS_REG);
	}

	read_from_rtc(RTC_SECONDS_REG);
	read_from_rtc(RTC_MINUTES_REG);
	read_from_rtc(RTC_HOURS_REG);
	read_from_rtc(RTC_DAYS_REG);
	read_from_rtc(RTC_WEEKDAYS_REG);
	read_from_rtc(RTC_MONTHS_CENTURY_REG);
	read_from_rtc(RTC_YEARS_REG);
	//pseudo_latch_aux|=0x02; // sounds beep at startup
	//pseudo_latch_aux|=(language&0x02);
	beep();
	PORTB|=((UART_LED_TX_OFF)|(UART_LED_RX_OFF)); // turns off led tx and rx (02/26/2016)
	TIMSK1=(1<<TOIE1); // An approx 1 second is call for update a temperature sensor and sense the voltage of the charger.

	// read EEPROM event
	readAlarmEEPROM();
	/*readPinoEEPROM(pino1, PINO1_OFFSET_ADDR);
	readPinoEEPROM(pino2, PINO2_OFFSET_ADDR);
	readPinoEEPROM(pino3, PINO3_OFFSET_ADDR);
	readPinoEEPROM(pino4, PINO4_OFFSET_ADDR);
	readPinoEEPROM(pino5, PINO5_OFFSET_ADDR);
	readPinoEEPROM(pino6, PINO6_OFFSET_ADDR);*/

	readPinoEEPROM(&pino1, PINO1_OFFSET_ADDR);
	readPinoEEPROM(&pino2, PINO2_OFFSET_ADDR);
	readPinoEEPROM(&pino3, PINO3_OFFSET_ADDR);
	readPinoEEPROM(&pino4, PINO4_OFFSET_ADDR);
	readPinoEEPROM(&pino5, PINO5_OFFSET_ADDR);
	readPinoEEPROM(&pino6, PINO6_OFFSET_ADDR);

	// end EEPROM event

	// Discard firt sensors read
	//read_sensor(TEMP1_SENSOR);
	//read_sensor(TEMP2_SENSOR);
	//read_sensor(B1_SENSOR);
	//read_sensor(B2_SENSOR);
	read_all_sensor();
	// End of discard
	clear_input(0);
	init_UART(EEPROM_read(UART_CONF_EEPROM_ADDRESS)); // initializing UART
	sei(); // set all interrupts

	for (;;)
	{

		_delay_ms(4);
		decodificar(); // decodifica o controle remoto
		read_kbd();


		//n=(cr_start==2) && (code_cr!=0xff);
		//if (n)
		//if (n)
		//if (((cr_start&0x06)>0)&&(menu<0xFF)) // 0xFF UART access LCD
		//if (cr_start&0x02) // depuração
		//if ((code_cr!=0xFF)&&(menu!=0xFF))
		if ((code_cr>0x01)&&(menu!=0xFF))
		{
/*
			cli();
			prepare_lcd();
				lcd_clear_line(3);
				//ultoa(key, conv, 16);
				ultoa(code_cr, conv, 16);
				print_lcd2(conv);
				//code_cr=0xFE;
			set_none();
			sei();
*/
			if ((code_cr==MENU_KEY)&&(menu==0x00)) show_initial_menu();
			else if (code_cr==RETURN_KEY)
			{
				if (menu==IS_MENU)
				{
					exit_menu();
/*					
					menu=0x00;
					prepare_lcd();
					clear_display();
					temporizador=1;
					set_none();
*/
				}

			}
			else if (code_cr==BEEP_ON_OFF)
			{
				//uses pseudo_latch_aux bit 1 as flag
				language^=BEEP_ENABLE;
				writeLanguageEEPROM();
				//pseudo_latch_aux^=0x02;

			}

			if (menu==IS_MENU)
			{
					if (code_cr=='1') show_set_date_time();
					else if (code_cr=='2') show_pino_menu();
					else if (code_cr=='3') show_sensor_menu();
					else if (code_cr=='4') show_menu_calculator();
					else if (code_cr=='5') show_other_menu();
					else if (code_cr=='6') about();
			}
			else if (menu==DATE_TIME_MENU)
			{
				if (code_cr==RETURN_KEY) show_initial_menu();
				else
				{
					switch (code_cr)
					{
						case '1': set_time_date();break;
						case '2': find_weekday(); break;
						case '3': set_alarm();
					}

				}
			}
			else if (menu==DATE_TIME_ADJUST)
			{
				insert_input(0);
				if (code_cr==RETURN_KEY) show_set_date_time();
				else if (code_cr==ENTER_KEY)
				{

					if (is_time_date_valid_input(0))
					{
						n=(DT.ss[0]-0x30)<<4;
						n|=(DT.ss[1]-0x30);
						write_to_rtc(n, RTC_SECONDS_REG);

						n=(DT.mm[0]-0x30)<<4;
						n|=(DT.mm[1]-0x30);
						write_to_rtc(n, RTC_MINUTES_REG);

						n=(DT.hh[0]-0x30)<<4;
						n|=(DT.hh[1]-0x30);						

						write_to_rtc(n, RTC_HOURS_REG);

						n=(DT.day[0]-0x30)<<4;
						n|=(DT.day[1]-0x30);						

						write_to_rtc(n, RTC_DAYS_REG);

						n=(DT.month[0]-0x30)<<4;
						n|=(DT.month[1]-0x30);
						if ((input[0]=='1')&&(input[1]=='9')) n|=0x80;
						write_to_rtc(n, RTC_MONTHS_CENTURY_REG);

						n=getDay(atoi(DT.year),atoi(DT.month),atoi(DT.day));
						write_to_rtc(n, RTC_WEEKDAYS_REG);

						n=(DT.year[2]-0x30)<<4;
						n|=(DT.year[3]-0x30);
						write_to_rtc(n, RTC_YEARS_REG);
					}
					clear_input(0);
				}
				else if (code_cr==CLEAR_KEY)
				{
					clear_input(1);
				}

			}
			else if (menu==DATE_TIME_WEEK_DAY)
			{
				insert_input(0);
				if  (code_cr==RETURN_KEY) show_set_date_time();
				else if (code_cr==ENTER_KEY)
				{
					if (is_time_date_valid_input(1))
					{
						prepare_lcd();
						lcd_clear_line(4);
						get_week_day((unsigned char)getDay(atoi(DT.year), atoi(DT.month),atoi(DT.day)));
						print_lcd2(conv);
						SetCursor(3,1);
						set_none();
					}
					clear_input(0);
				}
				else if (code_cr==CLEAR_KEY)
				{

					clear_input(1);

				}
			}
			else if (menu==ALARM_SETUP)
			{
				insert_input(0);
				if (code_cr==RETURN_KEY) show_set_date_time();
				else if (code_cr==ENTER_KEY)
				{
					prepare_lcd();
					lcd_clear_line(4);
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

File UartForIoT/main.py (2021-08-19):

import serial
from totcp import ToTcp
from monitore import monitore
#sum aug 15 22:55:41 -03 2021 
def main():
    """Main file application
    """

    print(serial.__file__)
    ser=serial.Serial(
        port='/dev/ttyUSB0',
        baudrate=9600,
        parity=serial.PARITY_NONE,
        stopbits=serial.STOPBITS_ONE,
        bytesize=serial.EIGHTBITS,
        timeout=0.1
    )
    address='192.168.1.78'
    #address='localhost'
    port=10000

    sender=ToTcp(address, port)

    monitore(sender, ser)

    sender.close()
    ser.close()

if __name__ == "__main__":
    main()

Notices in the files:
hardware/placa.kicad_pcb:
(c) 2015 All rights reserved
